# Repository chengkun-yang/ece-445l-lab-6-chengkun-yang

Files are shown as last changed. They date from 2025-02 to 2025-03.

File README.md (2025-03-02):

Review Assignment Due Date (https://classroom.github.com/a/TtMRZ3mh)
## 0 Repository Structure

The typical explanation for the repo structure. Lab specific instructions can be
found further below.

### 0.1 HW

The `hw` folder should contain your schematic and board files for your PCB or
circuits. In labs 1-5 and 10, you will be creating schematics for your circuit
in KiCad.

### 0.2 SW

The `sw` folder should contain your application firmware and software written
for the lab. The `sw/inc` folder contains firmware drivers written for you by
Professor Valvano. Feel free to write your own (in fact, in some labs, you may
be required to write your own).

You can place any other source files in the `sw` folder. TAs will look at the
files you create and/or modify for software quality and for running your
project.

### 0.3 Resources

A couple files are provided in the Resources folder so you don't have to keep
searching for that one TI document. Some of them are immediately useful, like
the TM4C datasheet. Others may be useful for your final project, like the
TM4C_System_Design_Guidelines page.

### 0.4 Git and Github

We will extensively use Git and Github for managing lab projects. This makes it
easier for TAs to grade and help debug the project by allowing us to see commit
histories, maintain a common project structure, and likewise, it makes it easier
for students to collaborate with partners, merge different codebases, and to
debug their work by having a history of commits.

Two common ways of using Git and Github are [Github Desktop](https://desktop.github.com/) and the [command line](https://git-scm.com/downloads).
[Tutorials](https://dev.to/mollynem/git-github--workflow-fundamentals-5496) are also abundant on the net for you to peruse. We've provided a cheatsheet for git
in the Resources folder.

It is highly recommended to make the most out of Git, even if you've never used
it before. Version control will save you a lot of suffering, and tools like Git
or SVN are ubiquitous in the industry.

A gitignore file is added to the root of this repo that may prevent specific
files from being tagged to the repo. This are typically autogenerated output
files we don't care about, but sometimes other stuff (like .lib files) falls
through that we want. Feel free to modify if necessary.

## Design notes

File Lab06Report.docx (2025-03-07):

Name: __Chengkun Yang

EID: __cy7496

Semester: Fall 2024

Course: ECE445L

A) Objectives:

1. In a few sentences, describe the purpose of the lab and the features of your alarm clock.

The purpose of this lab is to create a schematic for the alarm clock from lab 4, then converting it to a PCB and layout traces all within KiCAD. It features the tm4c chip instead of the full board and has reset / mode change switches. There are also plenty of bypass capacitors to prevent sudden changes in voltage along with routing to make the wire capacitance lower in critical subsystems.

B) Hardware Design Deliverables:

1. Deliverable 1: Using KiCad, create a schematic for your design. Include a screenshot in the space below.

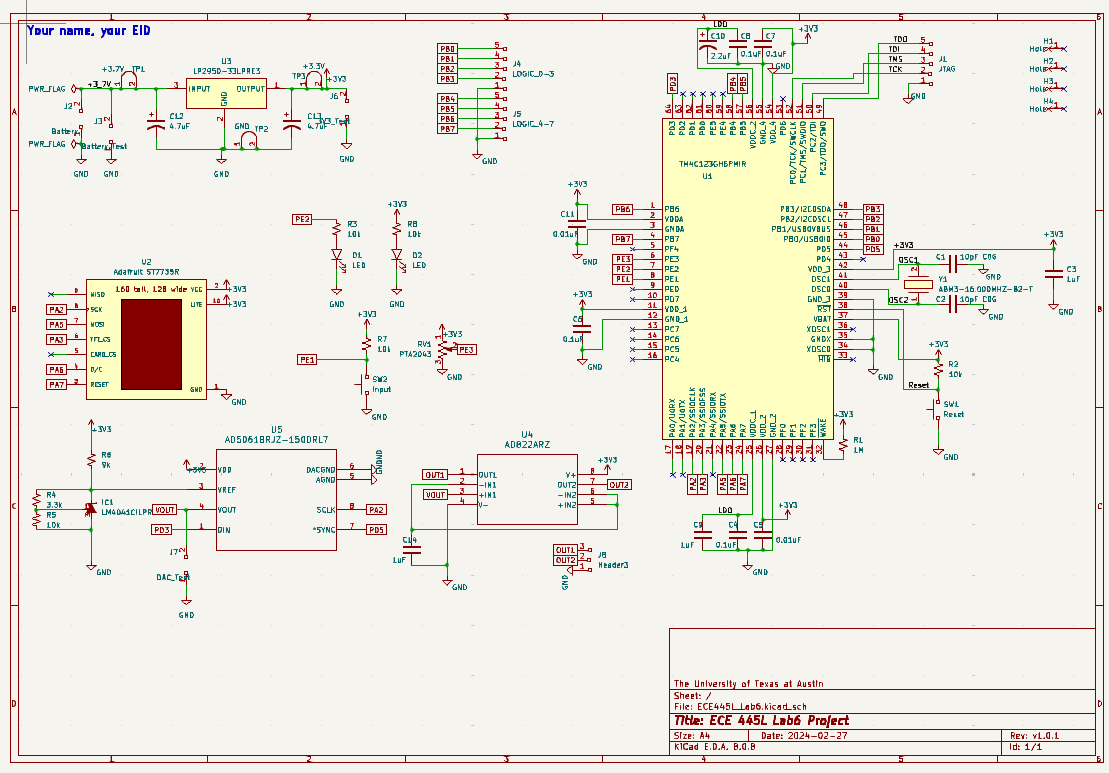
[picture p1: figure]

2. Deliverable 2: Using KiCad, create a Layout for your design. Include a screenshot in the space below.

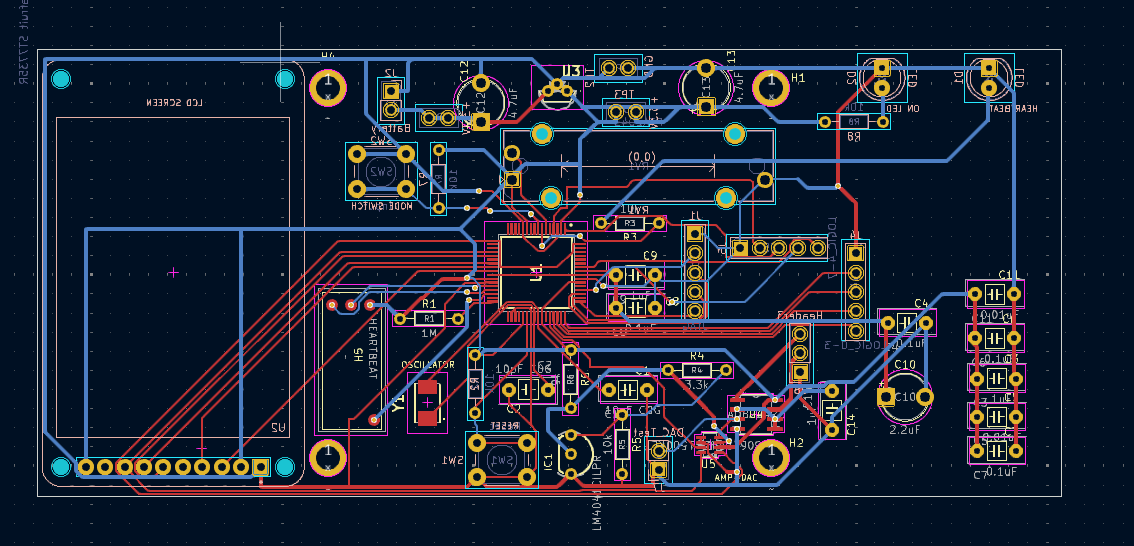
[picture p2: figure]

C) Software Design Deliverables:

1. I have pushed my project to GitHub for grading (Check box if true). ☒

D) Measurement Data:

1. Deliverable 3: Cardboard mockup of the PCB
2. Deliverable 4: I have updated the bill of materials (Check box if true). ☒
3. Deliverable 5: Estimated current usage

142.9 mA

4. Deliverable 6: JLC PCB Quote

$80.69

5. Deliverable 7 (4 or 8pt EC): Custom Symbol and Footprint

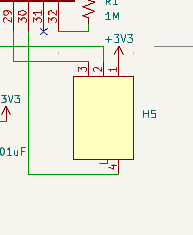
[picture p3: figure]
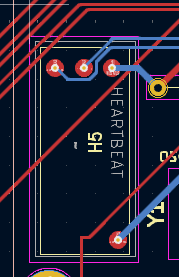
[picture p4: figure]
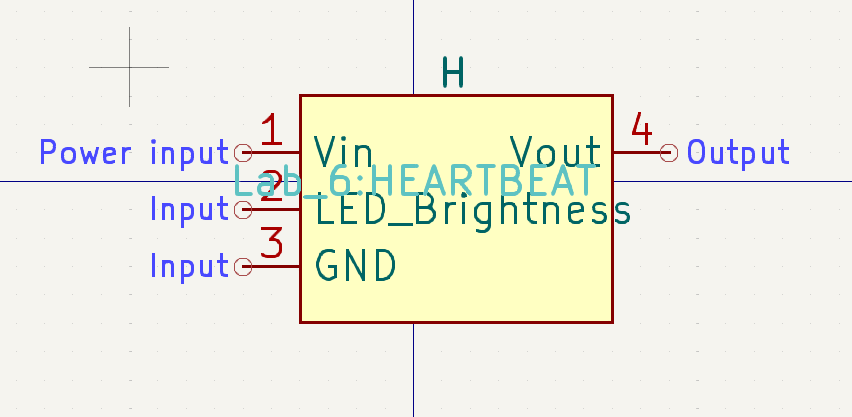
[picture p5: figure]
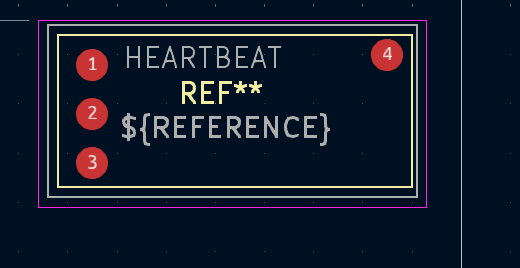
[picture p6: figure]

I did not show off my custom symbol during checkout, I just used the symbol editor and footprint editor in KiCAD and copied the footprint of other parts. For symbol I added 4 pins and labeled them as input/output/powerinput and for the footprint I added 3 layers of outline along with the silkscreen text and pins corresponding to the ones on the symbol.

E) Analysis and Discussion Questions:

1. Estimate how long the system you created would run on the 2600mA battery.

You do capacity/current to get around 18.2 hours.

2. Estimate the power dissipated through the LDO regulator knowing the current draw from downstream components and voltage drop across the regulator.

Since the voltage drop is 0.4V and the current draw is 142.9 mAh, the power dissipation is 0.0572W.

3. Examine the following excerpt from the datasheet for the MX1500 which has a nominal capacity of 2500mAh. Assuming you placed enough of these batteries in series to power your system, how long would the lifetime be? What happens to the lifetime of the battery when you double the current?

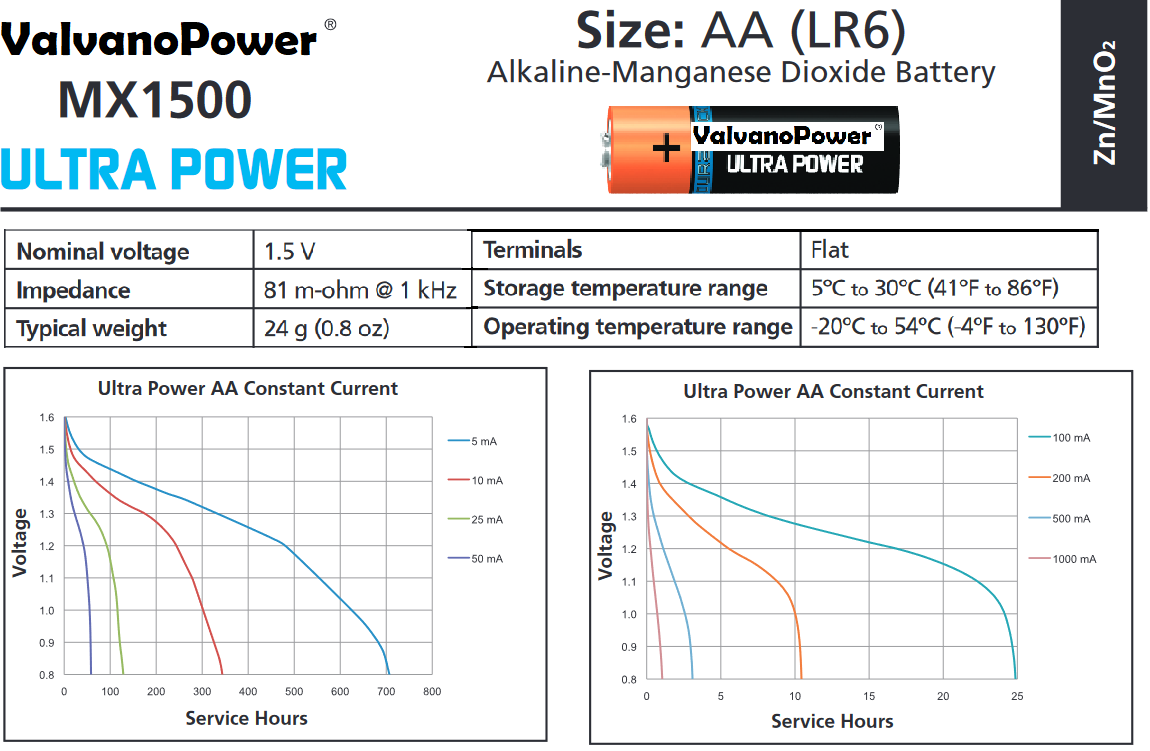
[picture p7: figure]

Since we need at least 3 in series to get >3.7V, the capacity would be 7500mAh which would be around 52.7 hours of lifetime. If the current is doubled, the lifetime halves.

4. Discuss the advantages and disadvantages of using an LDO versus a switching regulator.

LDOs are smaller in area and have low noise/output ripple. They are also cheaper and work with almost all power supplies with output variation. Unfortunately, they are less efficient, can only work with one predefined input voltage, can only output a single Vout lower than Vin, and work better with smaller current.

Lab 6 report ECE445L

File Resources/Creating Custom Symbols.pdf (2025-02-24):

## Creating Custom Symbols

## Contents

Creating Custom Symbols | 1

Introduction

KiCad is a powerful open-source software suite for electronic design automation (EDA). It offers a comprehensive set of tools for schematic capture and PCB layout. While KiCad comes with an extensive library of symbols and footprints, there are times when you may need to create custom symbols and footprints to suit specific components or devices not available in the standard libraries or online.

Creating custom symbols allows you to represent components accurately in your schematics, while custom footprints enable precise placement and routing of PCB components.

Creating a Custom Symbol

A symbol in KiCad represents a component on your schematic. Every component on a schematic must be precisely represented to ensure the functionality and reliability of the final product. While KiCad offers a vast library of pre-made symbols, there are instances where designers encounter unique components or specialized devices not covered by the standard offerings.

To create a symbol, open the symbol editor.

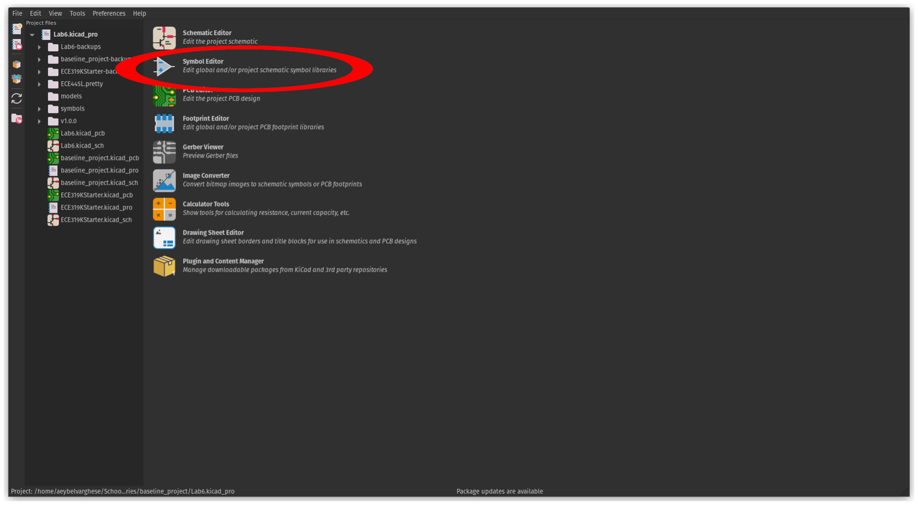
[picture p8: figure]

Figure 1: Main Menu

The KiCad Symbol Editor is a tool within the KiCad software suite specifically designed for creating and editing schematic symbols. It provides a user-friendly interface for designing graphical representations of electronic components, which are then used in schematics to illustrate circuit connections and layouts.

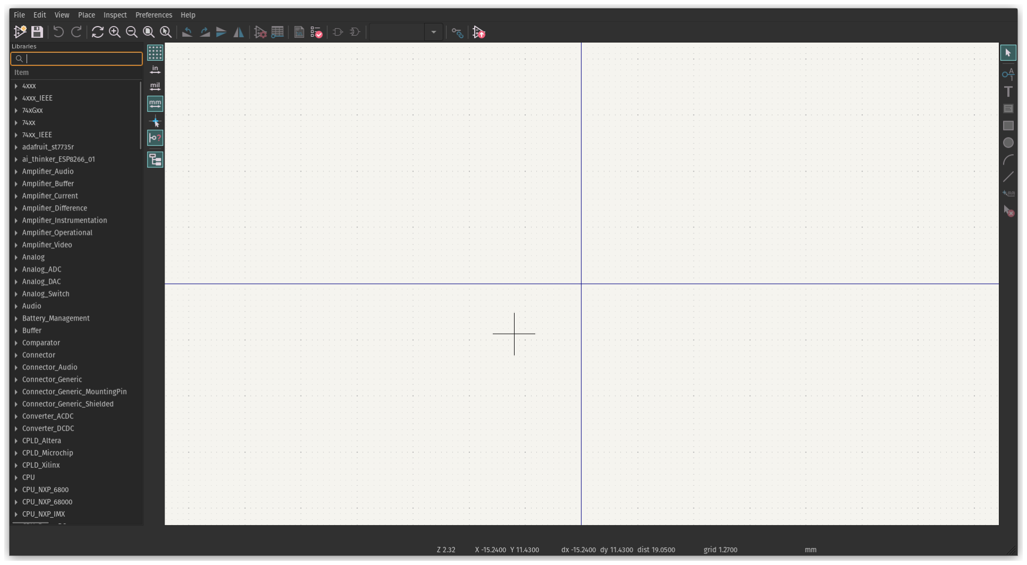
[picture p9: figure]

Figure 2: KiCad Symbol Editor

The Symbol Editor offers a graphical canvas where users can draw and manipulate schematic symbols using various drawing tools such as lines, arcs, polygons, and text boxes. The Symbol Editor allows users to save custom symbols to libraries for future use in other projects. Libraries can be organized and managed within KiCad to ensure easy access to custom symbols and efficient reuse across designs. Refer to the resource on adding libraries on more information regarding libraries.

When creating a symbol, it must be part of a library. We can either select a library to append a symbol to, or create a new library. To create a library, navigate to File → New Library, from here we can decide which symbol library table we want to add to, the global or project.

The global library table is shared amongst all your KiCad projects, while the project table is only for your currently open project. For this writeup, I am going to be adding it to the Project Table. When you press Ok, you can choose the location to save the “.kicad_sym” file which will contain your symbol library. You can choose any location you wish, although it is reccomended to have a folder dedicated for symbols organized in a reasonable matter. There is a “footprints” folder in the baseline project, and I will be storing the symbol library there. A entry in the symbol library table will be automatically made.

With a library selected in the left pane, press the “New Symbol Icon” or the Keyboard shortcut “N” to create a new symbol

Figure 3: Creating a symbol in the toolbar

Provide a name for the symbol, I am going to be creating a symbol for the MPU6050, (https://invensense.tdk.com/wp-content/uploads/2015/02/MPU-6000-Datasheet1.pdf) a IMU (Intertial Measurement Unit) from TDK InvenSense.

Creating symbols in KiCad involves designing graphical representations of electronic components to be used in schematics. Referring to datasheets during this process is crucial for accurately capturing the component’s electrical characteristics and pin configurations.

Referring to the pinout, we notice there are three categories of pins for this specific IC: power, communi-cation, and miscellaneous pins. We want to include all of these in our symbol. KiCad provides tools in the side toolbar to draw basic geometric shapes and describe pins.

Lets start by using the box tool to define the shape of our symbol.

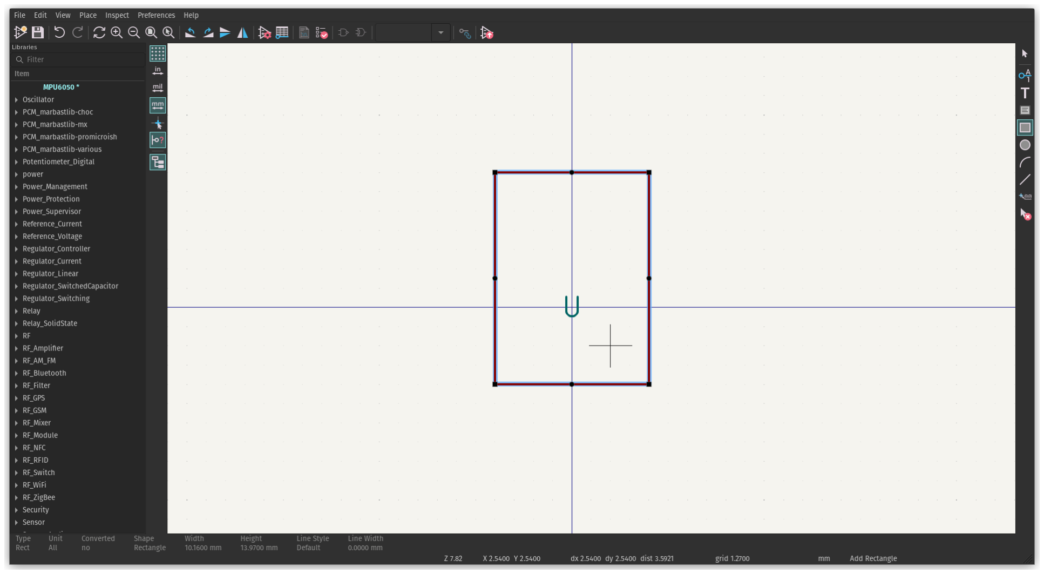
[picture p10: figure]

Figure 4: Box in Symbol Editor

With the shape of our pin assigned lets start adding pins. Select the “Add a Pin” button on the side toolbar, or press “P”.

When you press “Add a pin” in the KiCad Symbol Editor, you are prompted with several options to configure the properties of the pin being added to the symbol. These options allow you to define the electrical characteristics and behavior of the pin within the schematic symbol.

1. Name: This field allows you to specify the name of the pin, which is typically a descriptive label indicating the function or purpose of the pin within the component. Refer to the datasheet of the component for the name
2. Number: Here, you can assign a unique number to the pin. Pin numbers are used to identify individual pins within the symbol and are often based on the component’s datasheet or industry standards.
3. Orientation: This option determines the direction in which the pin is oriented within the symbol. You can choose from various orientations such as left, right, up, down.
4. Length: Specifies the length of the pin’s graphical representation within the symbol. This helps to visually distinguish pins of different lengths and aids in aligning pins with their corresponding connection points in the schematic.
5. Electrical Type: Defines the electrical characteristics of the pin, such as whether it is an input, output, bidirectional, power, or other special types. Selecting the appropriate electrical type ensures correct behavior during circuit simulation and layout as well as good for organization.
6. Visible: Determines whether the pin is visible or hidden in the symbol. Hidden pins are often used for internal connections or other purposes where the pin should not be displayed on the schematic.
7. Pin Function: This option allows you to specify additional information about the pin’s function or behavior, such as whether it is a clock input, reset signal, or other specialized function. This information aids in documentation and understanding the purpose of each pin within the symbol.

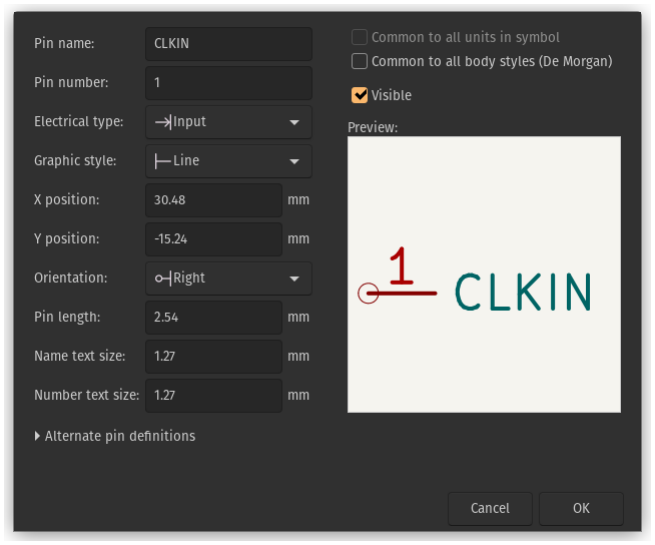
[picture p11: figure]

Figure 5: Describing a pin

Once we submit the options for the pin, we can place the pin down on our symbol.

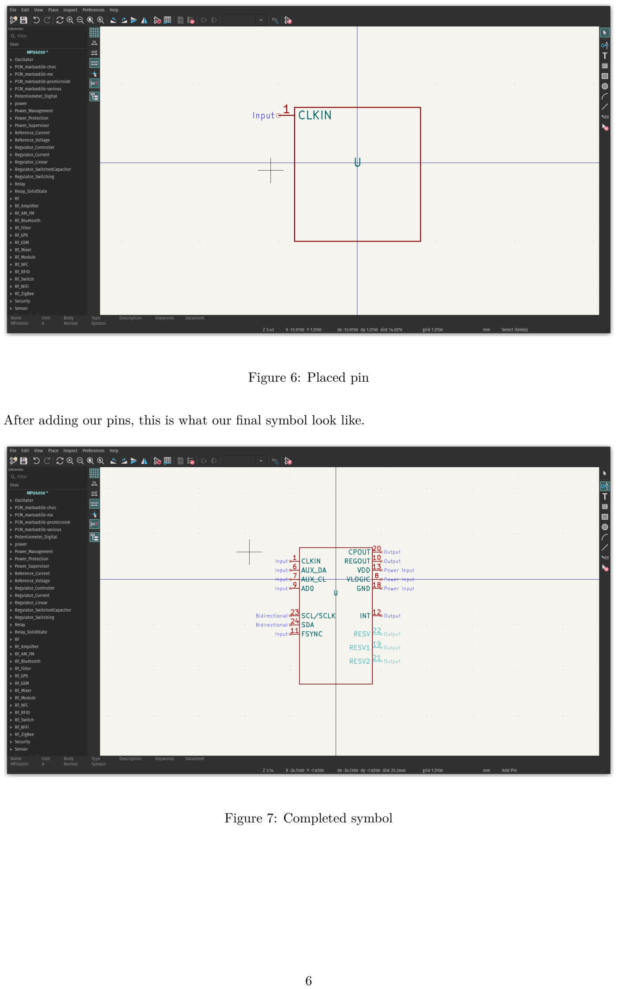
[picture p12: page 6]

Figure 6: Placed pin

After adding our pins, this is what our final symbol look like.

Figure 7: Completed symbol

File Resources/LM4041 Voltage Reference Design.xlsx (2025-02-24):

Goal: design a shunt reference circuit
Jonathan Valvano, EE445L
Desired Vz | 1.5 | volts | 1) pick a desired reference voltage Vz (volts)
Vref | 1.233 | volts | LM4041 parameter
R1 | 47 | kohm | 2) choose a standard resistance value (kohm)
best R2 | 10.17761557 | kohm
Pick R2 | 10 | kohm | 3) pick a standard value for R2 close to best R2
Actual Vref | 1.495340426 | volts | Vz=Vref(1+R2/R1)
Vs | 3.3 | volts | V supply
Rin | 2 | kohm | 4) estimate input impedence on Vz (e.g., to DAC)
Iz | 0.08 | mA | LM4041 parameter
Iref | 0.02623404255 | mA | Vz/(R1+R2), Ohms Law, current through R1,R2
IL | 0.7476702128 | mA | Vz/Rin, Ohms Law, current through Rin
I total | 0.8539042553 | mA | Iz+Iref+IL
max Rs | 2.113421456 | kohm | (Vs-Vz)/Itotal
 |  |  | 5) choose Rs less than max Rs

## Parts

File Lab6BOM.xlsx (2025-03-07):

Bill of Materials |  |  | Lab 6
ECE445L Fall 2024 |  |  | $80.69
Qty Note | REF DES Note (http://projects.ece.utexas.edu/valvano/wiki/doku.php?id=pcbartist:schematics)
Quantity | REF DES | Type | Description | Manufacturer | Mfg. P/N | Distributor | P/N | Unit cost | Cost | Estimated Current | Inventory
1 | J2 | BAT | Li-ion Cylindrical 3.7V 2600mAh Battery | Tenergy | 18650 |  |  | $8.00 | $8.00 |  | https://power.tenergy.com/tenergy-li-ion-18650-cylindrical-3-7v-2600mah-flat-top-rechargeable-battery-ul-listed-mh48285
1 | U5 | DAC | 16bit 4LSB buffered DAC in SOT23 | Analog Devices | AD5061BRJZ-1500RL7 | Mouser | 584-AD5061BRJZ1500R7 | $10.15 | $10.15 | 1.2mA
1 | U4 | AMP | IC OPAMP GP 2 CIRCUIT 8SOIC | Analog Devices | AD822ARZ | DigiKey | 505-AD822ARZ-ND | $12.33 | $12.33 | 20mA
1 | N/A | BOX | Enclosures, Boxes, & Cases 1593Y W/ALUM PANEL BLACK | Hammond | 1593YALBK | Mouser | 546-1593YALBK | $9.83 | $9.83
2 | SW1, SW2 | SW | SWITCH TACTILE SPST-NO 0.05A 12V | C&K | PTS526SK15SMTR2 LFS | DigiKey | CKN12221-1-ND | $0.13 | $0.26
1 | U2 | DIS | GRAPHIC DISPLAY TFT RGB 1.8" | Adafruit | 358 | DigiKey | 1528-1536-ND | $19.95 | $19.95 | 0.7mA
1 | U3 | LDO | IC REG LINEAR 3.3V 100MA TO92-3 | TI | LP2950-33LPE3 | DigiKey | 296-26120-ND | $1.15 | $1.15 | 100mA
2 | D1, D2 | LED | LED RED DIFFUSED T-1 3/4 T/H | Kingbright | WP7113ID | DigiKey | 754-1264-ND | $0.21 | $0.42 | 20mA
1 | RV1 | POT | SLIDE POT 10K OHM 0.1W TOP 20MM | Bourns | PTA2043-2015CPB103 | DigiKey | PTA2043-2015CPB103-ND | $1.44 | $1.44
1 | IC1 | VREF | IC VREF SHUNT ADJ 0.5% TO92-3 | TI | LM4041CILPR | DigiKey | 296-22173-1-ND - Cut Tape (CT) | $1.06 | $1.06
5 | R2, R3, R5, R7, R8 | RES | RES 10K OHM 1% 1/4W AXIAL | YAGEO | MFR-25FRF52-10K | DigiKey | 13-MFR-25FRF52-10KCT-ND | $0.10 | $0.50
4 | R4, R6 | RES | RES 3K OHM 5% 1/4W AXIAL | Stackpole Electronics Inc | CF14JT3K00 | DigiKey | CF14JT3K00CT-ND | $0.10 | $0.40
1 | U1 | IC | IC MCU 32BIT 256KB FLASH 64LQFP | TI | TM4C123GH6PMI | DigiKey | 296-35848-ND | $13.02 | $13.02 | 1mA
2 | C12, C13 | CAP | CAP CER 4.7UF 10V X5R 0603 | Samsung Electro-Mechanics | CL10A475KP8NNNC | DigiKey | 1276-1044-1-ND | $0.08 | $0.16
4 | C4, C6, C7, C8 | CAP | CAP CER 0.1UF 10V X7R 0402 | Samsung Electro-Mechanics | CL05B104KP5NNNC | DigiKey | 1276-1002-1-ND | $0.08 | $0.32
3 | C3, C9, C14 | CAP | CAP CER 1UF 25V X7R 0603 | Samsung Electro-Mechanics | CL10B105KA8NNNC | DigiKey | 1276-1184-1-ND | $0.08 | $0.24
1 | C10 | CAP | CAP CER 2.2UF 10V X7R 0603 | Samsung Electro-Mechanics | CL10B225KP8NNNC | DigiKey | 1276-1134-1-ND | $0.08 | $0.08
2 | C5, C11 | CAP | CAP CER 0.01UF 10V X7R 0201 | Taiyo Yuden | MAASL063SB7103MFCA01 | DigiKey | 587-MAASL063SB7103MFCA01CT-ND | $0.11 | $0.22
2 | C1, C2 | CAP | CAP CER 10PF 50V C0G/NP0 0402 | Murata Electronics | GRM1555C1H100FA01D | DigiKey | 490-6186-1-ND | $0.10 | $0.20
1 | Y1 | OSC | CRYSTAL 16.0000MHZ 18PF SMD | Abracon LLC | ABM3-16.000MHZ-B2-T | DigiKey | 535-9103-1-ND | $0.96 | $0.96
 |  |  |  |  |  |  |  |  |  |  |  | 5 CD
 |  |  |  |  |  |  |  |  |  |  | http://www.kemet.com/kemet/web/homepage/kechome.nsf/vapubfiles/F3101_GoldMax.pdf/$file/F3101_GoldMax.pdf

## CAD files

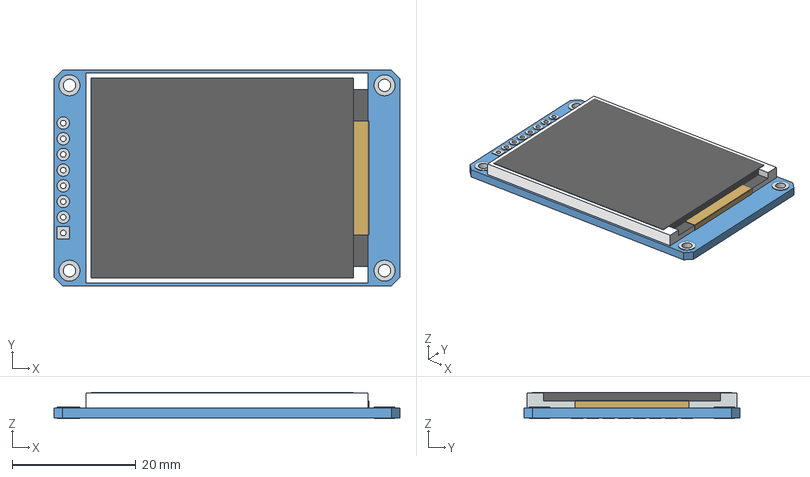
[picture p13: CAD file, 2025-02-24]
hw/Part Libraries/models/adafruit_st7735r.stp
56.0 x 35.0 x 4.25 mm

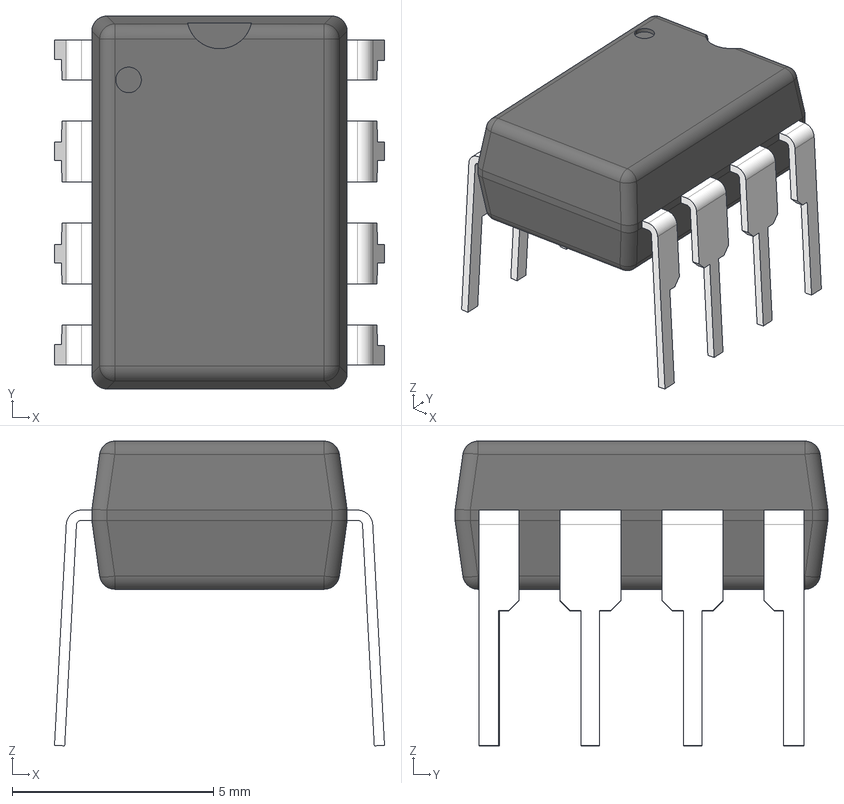
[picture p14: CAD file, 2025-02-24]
hw/Part Libraries/models/ti_TLV5618AIP.stp
8.20 x 9.27 x 7.58 mm
BODY_P0008A
LEAD_P0008A x 4
LD_LHALF_P0008A x 2
LD_RHALF_P0008A x 2

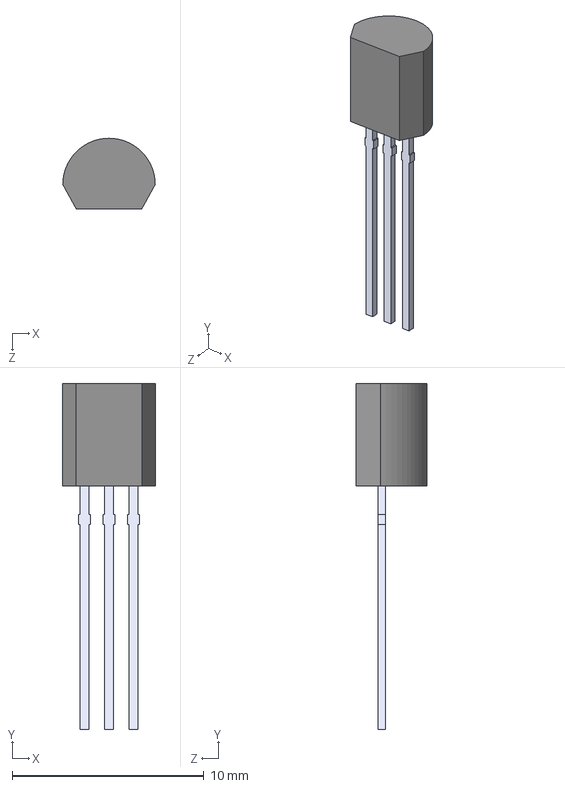
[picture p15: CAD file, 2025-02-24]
hw/Part Libraries/models/ti_LM4041CILPR.step
4.82 x 18.0 x 3.68 mm

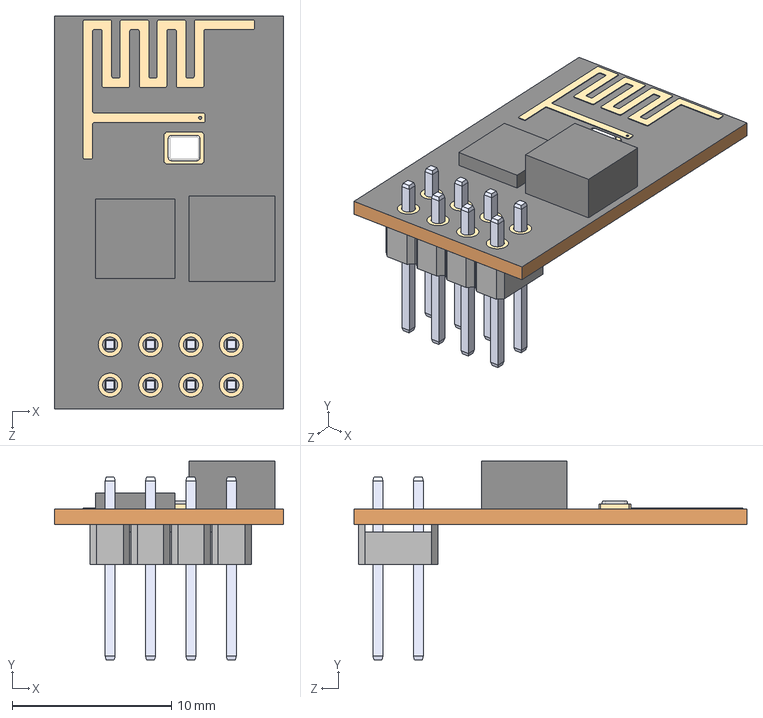
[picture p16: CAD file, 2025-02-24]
hw/Part Libraries/models/ai_thinker_ESP8266-01.step
14.4 x 12.5 x 24.7 mm

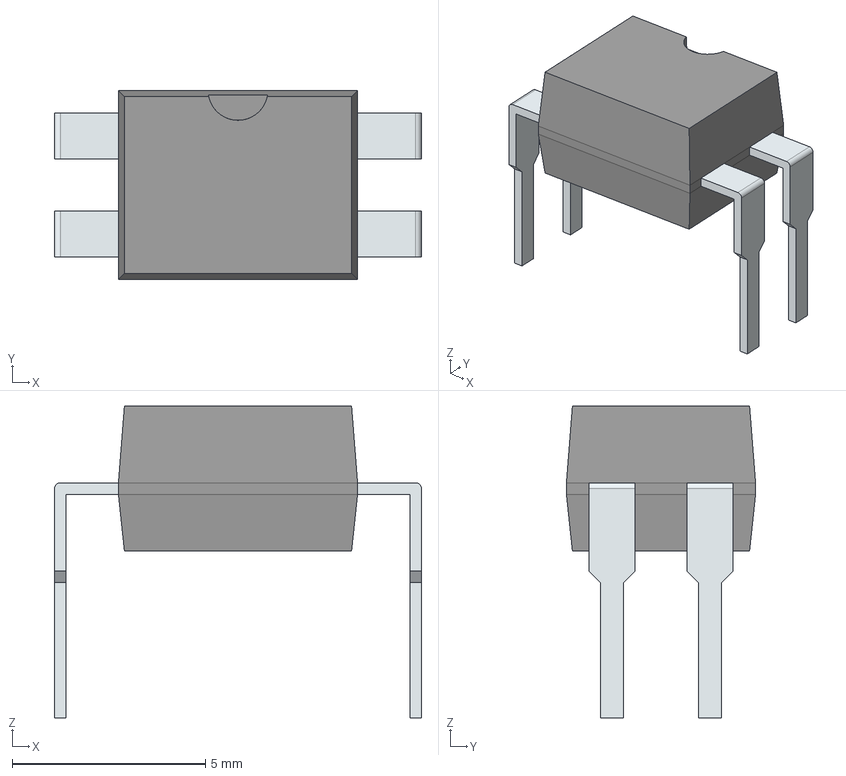
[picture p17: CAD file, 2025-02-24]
hw/Part Libraries/models/vishay_IRLD024PBF.stp
9.51 x 4.90 x 8.07 mm
PinsArrayLR

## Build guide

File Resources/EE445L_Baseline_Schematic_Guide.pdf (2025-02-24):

# EE445L – Fall 2021

Lab Baseline Schematic Guide: Rev 10-1-2021 | Page 1

### McDermott & Valvano

This semester we have decided to standardize the I/O Pin assignment to make remote debugging a little

### bit easier for the TAs. The standardized Signal and Port assignments are listed below:

PORT | SIGNAL NAME | TM4C PORT ASSIGNMENT | NOTES
Port-A[2] | ST7735_SCK | SSI0_SCK | SSI interface to the ST7735 LCD
Port-A[3] | ST7735_TFT_CS | SSI0_SS
Port-A[4] | ST7735_MISO | SSI0_MISO
Port-A[5] | ST7735_MOSI | SSI0_MOSI
Port-A[6] | ST7735_DC | GPIO
Port-A[7] | ST7735_RST | GPIO
PORT | SIGNAL NAME | TM4C PORT ASSIGNMENT | NOTES
Port-B[0] | ST7735_CARD_CS | GPIO | ST7735 SDCARD Chip Select
Port-B[1] | PB1 | GPIO | Used for simple speaker
Port-B[2] | PB2 | GPIO/I2C0_SCK | Primarily GPIO, can be used for I2C
Port-B[3] | PB3 | GPIO/I2C0_SDA
Port-B[4] | TACH2 | T1_CCP0 | Tach Input for Lab-10
Port-B[5] | PB5 | GPIO/AIN_11 | GPIO or Analog input
Port-B[6] | PWM | M0_PWM0 | PWM control for Lab-10
Port-B[7] | PB7 | GPIO/PWM1
PORT | SIGNAL NAME | TM4C PORT ASSIGNMENT | NOTES
Port-C[4] | UP | GPIO | Used for switches in Lab 3
Port-C[5] | RIGHT | GPIO
Port-C[6] | LEFT | GPIO
Port-C[7] | DOWN | GPIO
PORT | SIGNAL NAME | TM4C PORT ASSIGNMENT | NOTES
Port-D[0] | SSI1_SCK | SSI1_SCK | SCK to TLV5616 DAC
Port-D[1] | SSI1_FS | SSI1_FS | SS/FS to TLV5616 DAC
Port-D[2] | PD2 | AIN_5 | Used to monitor DAC_OUT
Port-D[3] | SSI1_MOSI | SSI1_MOSI | MOSI to TLV5616 DAC
Port-D[6] | PD6 | GPIO | Can be used as alternate UART Port
Port-D[7] | PD7 | GPIO
PORT | SIGNAL NAME | TM4C PORT ASSIGNMENT | NOTES
Port-E[0] | 8266_GPIO_2 | GPIO | Status signal 8266 WiFi
Port-E[1] | RSTB_8266 | GPIO | Reset signal to 8266 WiFi
Port-E[2] | AIN_1 | AIN1 | Used for Audio Input Lab-9
Port-E[3] | GPIO | GPIO
Port-E[4] | 8266_TX 8266_RX | U5_RX U5_TX | UART TXD/RXD to 8266 WiFi Port-E[5]
PORT | SIGNAL NAME | TM4C PORT ASSIGNMENT | NOTES
Port-F[0] | LAUNCHPAD_SW2 | RESERVED for Launchpad | Mode Switch
Port-F[1] | RED_LED | | Red LED on LaunchPad
Port-F[2] | BLUE_LED | | Blue LED on LaunchPad
Port-F[3] | GREEN_LED | | Green LED on LaunchPad
Port-F[4] | LAUNCHPAD_SW1 | | Mode Switch
The baseline schematic printout is shown on the next two pages. Use this as the starting point for Eagle

### Schematics

Lab Baseline Schematic Guide: Rev 10-1-2021 | Page 2

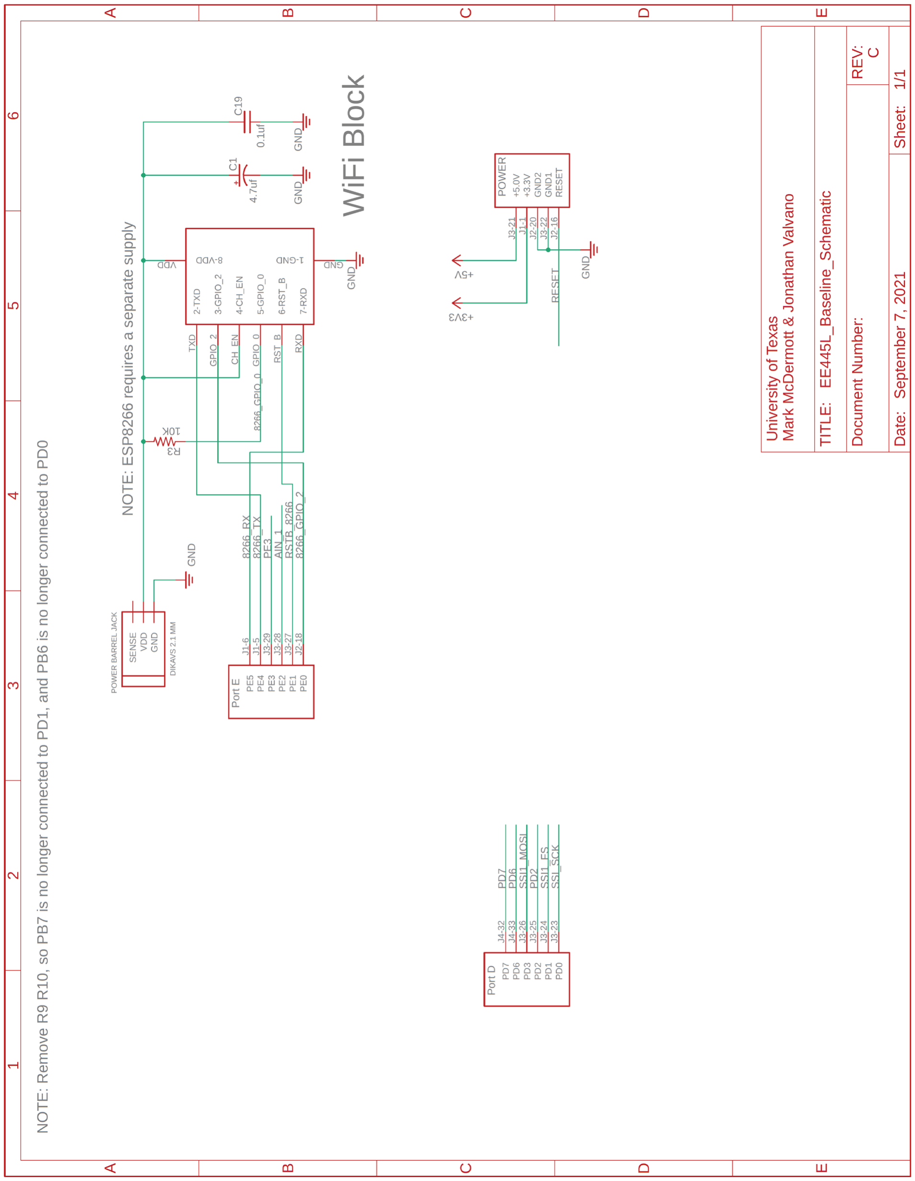
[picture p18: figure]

Lab Baseline Schematic Guide: Rev 10-1-2021 | Page 3

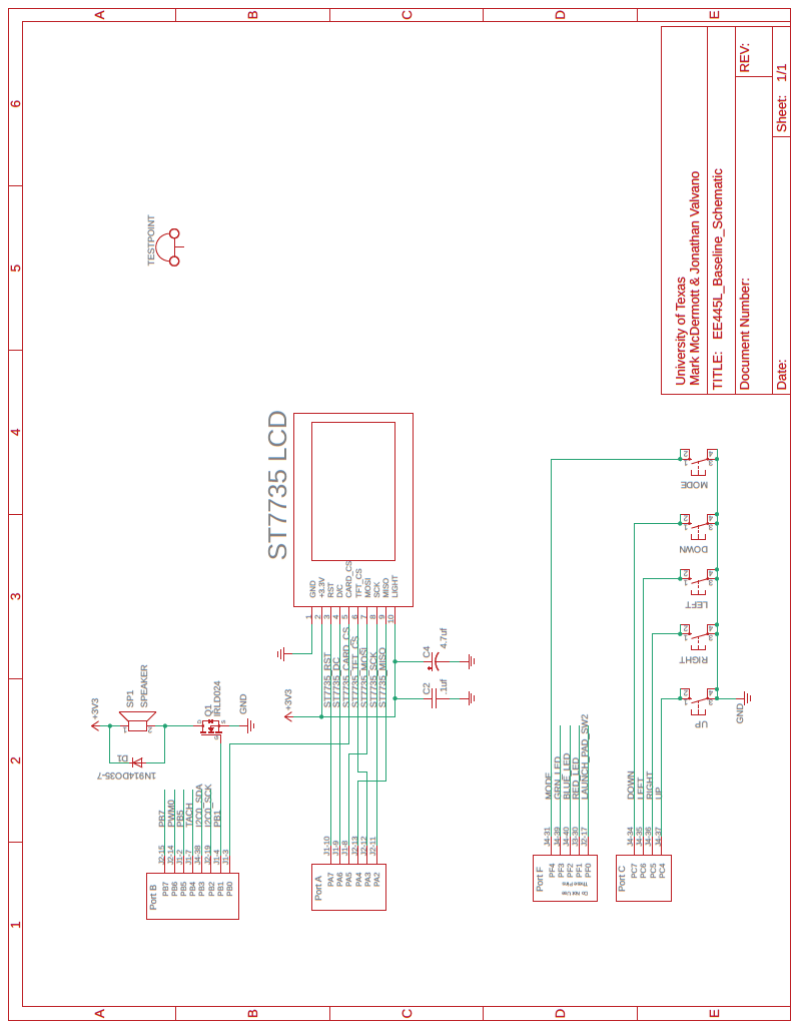
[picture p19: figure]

Lab Baseline Schematic Guide: Rev 10-1-2021 | Page 4

### PORT Initialization

Do not use this code without confirming that it does what you need it to do.

// ---------------------------------------------------------------------------//
// File name: Unified_Port_Init.c
//
// Author: | Mark McDermott
// Orig gen date: July 12, 2020
// Last update: August 17, 2020
//
// Description: This is the unified Port initialization routine 445L Labs
//
// Usage: | Call Lab_Brd_Port_Init () if you want to initialize all ports (preferred)
// | Call the individual port inits as needed.
//
// ---------------------------------------------------------------------------

#include "inc/tm4c123gh6pm.h"

#include "inc/Lab_Brd_Port_Init.h"

// --------------------------- | Port_Init | ------------------------------

void Lab_Brd_Port_Init(void){
Port_A_Init();
Port_B_Init();
Port_C_Init();
Port_D_Init();
Port_E_Init();
Port_F_Init();
}

// ----------------------------------------------------------------------------
// ---------------- | PORT A Initialization | --------------------------------
// ----------------------------------------------------------------------------//
// Port A drives the ST7735 LCD
//
// Backlight (pin 10) connected to +3.3 V
// MISO | (pin 9) connected to PA4
// SCK | (pin 8) connected to PA2 (SSI0Clk)
// MOSI | (pin 7) connected to PA5 (SSI0Tx)
// TFT_CS | (pin 6) connected to PA3 (SSI0Fss)
// CARD_CS | (pin 5) connected to PB0 (GPIO)
// Data/CMD (pin 4) connected to PA6 (GPIO)
// RESET | (pin 3) connected to PA7 (GPIO)
// VCC | (pin 2) connected to +3.3 V
// Gnd | (pin 1) connected to ground
//

void Port_A_Init(void){

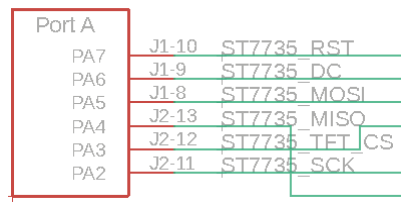
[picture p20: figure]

SYSCTL_RCGCSSI_R | |= 0x01; | // Activate SSI0
SYSCTL_RCGCGPIO_R | |= 0x01; | // Activate port A
while((SYSCTL_PRGPIO_R & 0x01)==0){}; | // allow time for clock to start
GPIO_PORTA_DIR_R | |= 0xC8; | // make PA3,6,7 out
GPIO_PORTA_AFSEL_R | &= ~0xC8; | // disable alt funct on PA3,6,7

Lab Baseline Schematic Guide: Rev 10-1-2021 | Page 5
GPIO_PORTA_DEN_R | |= 0xC8; | // enable digital I/O on PA3,6,7

// configure PA3,6,7 as GPIO
GPIO_PORTA_PCTL_R | = (GPIO_PORTA_PCTL_R
| & 0x00FF0FFF)
| + 0x00000000;
GPIO_PORTA_AMSEL_R | &= ~0xC8; | // disable analog functionality on PA3,6,7

// initialize SSI0
GPIO_PORTA_AFSEL_R | |= 0x2C; | // enable alt funct on PA2,3,5
GPIO_PORTA_DEN_R | |= 0x2C; | // enable digital I/O on PA2,3,5

// configure PA2,3,5 as SSI
GPIO_PORTA_PCTL_R | = (GPIO_PORTA_PCTL_R
| & 0xFF0F00FF)
| + 0x00202200;
GPIO_PORTA_AMSEL_R | &= ~0x2C; | // disable analog functionality on PA2,3,5
SSI0_CR1_R | &= ~SSI_CR1_SSE; | // disable SSI
SSI0_CR1_R | &= ~SSI_CR1_MS; | // master mode

// configure for system clock/PLL baud clock source
SSI0_CC_R | = (SSI0_CC_R&~SSI_CC_CS_M)
| + SSI_CC_CS_SYSPLL;

// clock divider for 8 MHz SSIClk (80 MHz PLL/24) // SysClk/(CPSDVSR*(1+SCR))
// 80/(10*(1+0)) = 8 MHz (slower than 4 MHz)
SSI0_CPSR_R | = (SSI0_CPSR_R
&~SSI_CPSR_CPSDVSR_M)
| + 10; | // must be even number

// SCR = 0 (8 Mbps data rate)
// SPH = 0
// SPO = 0
SSI0_CR0_R | &= ~(SSI_CR0_SCR_M
| | SSI_CR0_SPH
| | SSI_CR0_SPO);

// FRF = Freescale format
SSI0_CR0_R | = (SSI0_CR0_R
| &~SSI_CR0_FRF_M)
| + SSI_CR0_FRF_MOTO;

// DSS = 8-bit data
SSI0_CR0_R | = (SSI0_CR0_R
| &~SSI_CR0_DSS_M)
| + SSI_CR0_DSS_8;
// enable SSI
SSI0_CR1_R | |= SSI_CR1_SSE;

}

Lab Baseline Schematic Guide: Rev 10-1-2021 | Page 6

// ----------------------------------------------------------------------------
// ---------------- | PORT B Initialization | --------------------------------
// ----------------------------------------------------------------------------
//
// PB7 = GPIO/M0PWM1
// PB6 = PWM Output to Motor (M0PWM0)
// PB5 = GPIO/AIN11
// PB4 = Timer Capture input (TACH) // PB3 = GPIO/I2C_SDA
// PB2 = GPIO/I2C0_SCL
// PB1 = GPIO
// PB0 = ST7735 Card CS

void Port_B_Init(void){

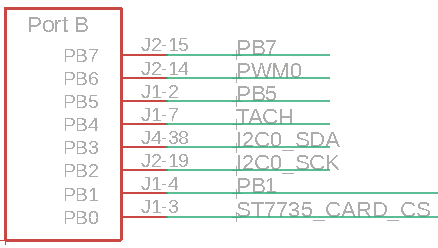
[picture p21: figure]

SYSCTL_RCGCPWM_R | |= 0x01; | // activate PWM0
SYSCTL_RCGCGPIO_R | |= 0x02; | // activate port B
while((SYSCTL_PRGPIO_R & 0x02) == 0){}; | // Wait

// --------------- Initialize PB7 as M0PWM1 -----------------------

GPIO_PORTB_AFSEL_R | |= 0x80; | // enable alt funct on PB7
GPIO_PORTB_PCTL_R | &= ~0xF0000000; | // configure PB7 as M0PWM1
GPIO_PORTB_PCTL_R | |= 0x40000000;
GPIO_PORTB_AMSEL_R | &= ~0x80; | // disable analog functionality on PB7
GPIO_PORTB_DEN_R | |= 0x80; | // enable digital I/O on PB7

// --------------- Initialize PB6 as M0PWM0 -----------------------
GPIO_PORTB_AFSEL_R | |= 0x40; | // enable alt funct on PB6
GPIO_PORTB_PCTL_R | &= ~0x0F000000; | // configure PB6 as PWM0
GPIO_PORTB_PCTL_R | |= 0x04000000;
GPIO_PORTB_AMSEL_R | &= ~0x40; | // disable analog functionality on PB6
GPIO_PORTB_DEN_R | |= 0x40; | // enable digital I/O on PB6

// --------------- Initialize PB5 as AIN11 -----------------------
GPIO_PORTB_DIR_R | &= ~0x20; | // make PB5 input
GPIO_PORTB_AFSEL_R | |= 0x20; | // enable alternate function on PB5
GPIO_PORTB_DEN_R | &= ~0x20; | // disable digital I/O on PB5
GPIO_PORTB_AMSEL_R | |= 0x20; | // enable analog functionality on PB5

// ----------------- Initialize PB4 as Timer Capture input (T1CCP0) ---------
GPIO_PORTB_DIR_R | &= ~0x10; | // make PB4 input
GPIO_PORTB_AFSEL_R | |= 0x10; | // enable alt funct on PB4
GPIO_PORTB_DEN_R | |= 0x10; | // enable digital I/O on PB4
| | // configure PB4 (T1CCP0)
GPIO_PORTB_PCTL_R | = (GPIO_PORTB_PCTL_R
| & 0xFFF0FFFF)
| + 0x00070000;
GPIO_PORTB_AMSEL_R | &= ~0x10; | // disable analog functionality on PB4

// ----------------- Initialize PB3-0 as GPIO ---------
GPIO_PORTB_PCTL_R | &= ~0x0000FFFF; | // GPIO
GPIO_PORTB_DIR_R | |= 0x0F; | // make PB3-0 out
GPIO_PORTB_AFSEL_R | &= ~0x0F; | // regular port function
GPIO_PORTB_DEN_R | |= 0x0F; | // enable digital I/O on PB3-0
GPIO_PORTB_AMSEL_R | &= ~0x0F; | // disable analog functionality on PB3-0
}

Lab Baseline Schematic Guide: Rev 10-1-2021 | Page 7

// ----------------------------------------------------------------------------
// ---------------- | PORT C Initialization | --------------------------------
// ----------------------------------------------------------------------------
//
// PC4 = UP switch
// PC5 = RIGHT switch
// PC6 = LEFT switch
// PC7 = DOWN switch
//

void Port_C_Init(void){

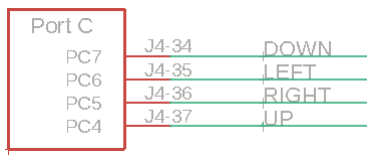
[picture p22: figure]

SYSCTL_RCGCGPIO_R | |= 0x04; | // Activate clock for Port C
while((SYSCTL_PRGPIO_R & 0x04) != 0x04){}; // Allow time for clock to start
GPIO_PORTC_PCTL_R | &= ~0xFFFF0000; | // regular GPIO
GPIO_PORTC_AMSEL_R | &= ~0xF0; | // disable analog function
GPIO_PORTC_DIR_R | &= ~0xF0; | // inputs on PC7-PC4
GPIO_PORTC_AFSEL_R | &= ~0xF0; | // regular port function
GPIO_PORTC_DEN_R | |= 0xF0; | // enable digital port
}

Lab Baseline Schematic Guide: Rev 10-1-2021 | Page 8

// ----------------------------------------------------------------------------
// ---------------- | PORT D Initialization | --------------------------------
// ----------------------------------------------------------------------------
//
// PD7 = GPIO/U2TX
// PD6 = GPIO/U2RX
// PD5 = Reserved for LaunchPad // PD4 = Reserved for Launchpad // PD3 = SSI1_MOSI (to TLV5616) // PD2 = AIN5
// PD1 = SSI1_FS/CS (to TLV5616) // PD0 = SSI1_SCK (to TLV5616)

void Port_D_Init(void){

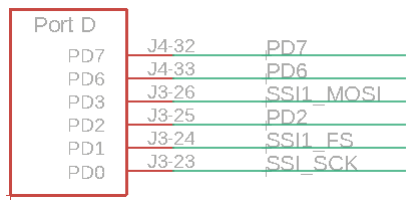
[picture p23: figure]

SYSCTL_RCGCGPIO_R | |= 0x08; | // activate port D
while((SYSCTL_PRGPIO_R & 0x08)==0){}; | // allow time for clock to stabilize

// --------------- Initialize PB7 as U2TX, PB6 as U2RX -----------------------

GPIO_PORTD_LOCK_R | = 0x4C4F434B; | // unlock REQUIRED for PD7
GPIO_PORTD_CR_R | |= 0xC0; | // commit PD6, PD7
GPIO_PORTD_AMSEL_R | &= ~0xC0; | // disable analog functionality on PD6, PD7
GPIO_PORTD_AFSEL_R | |= 0xC0; | // enable alternate function on PD6, PD7
GPIO_PORTD_DEN_R | |= 0xC0; | // enable digital on PD6, PD7 (PD6 is U2RX, PD7 is
U2TX)
GPIO_PORTD_PCTL_R =(GPIO_PORTD_PCTL_R
& 0x00FFFFFF)
| 0x11000000; // configure PD6, PD7 as UART

// --------------- Initialize PD2 as AIN5 ----------------------------------

GPIO_PORTD_DIR_R | &= ~0x04; | // make PD2 input
GPIO_PORTD_AFSEL_R | |= 0x04; | // enable alternate function on PD2
GPIO_PORTD_DEN_R | &= ~0x04; | // disable digital I/O on PD2
GPIO_PORTD_AMSEL_R | |= 0x04; | // enable analog functionality on PD2
// --------------- Initialize PD3,1,0 as SSI1 MOSI, FS & SCK ----------------
GPIO_PORTD_AMSEL_R | &= ~0x0B; | // disable analog functionality on PD
GPIO_PORTD_AFSEL_R | |= 0x0B; | // enable alt funct on PD3,1,0
GPIO_PORTD_DEN_R | |= 0x0B; | // enable digital I/O on PD3,1,0
GPIO_PORTD_PCTL_R | = (GPIO_PORTD_PCTL_R
& 0xFFFF0F00)
+ 0x00002022;
}

Lab Baseline Schematic Guide: Rev 10-1-2021 | Page 9

// ----------------------------------------------------------------------------
// ---------------- | PORT E Initialization | --------------------------------
// ----------------------------------------------------------------------------
//
// PE5 = 8266_RX (U5TX)
// PE4 = 8266_TX (U5RX)
// PE3 = GPIO
// PE2 = AIN_1 (Audio Input) // PE1 = 8266_8266
// PE0 = 8266_ GPIO_2

void Port_E_Init(void){

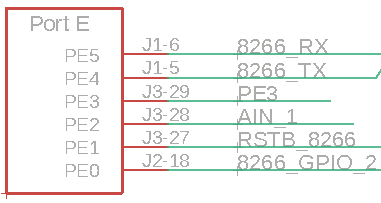
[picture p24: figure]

SYSCTL_RCGCGPIO_R | |= 0x10; | // activate port E
while((SYSCTL_PRGPIO_R & 0x10)==0){};

// --------------- Initialize PE5 as U5TX, PE4 as U5RX -----------------------

GPIO_PORTE_AFSEL_R | |= 0x30; | // enable alt funct on PE5-4
GPIO_PORTE_DEN_R | |= 0x30; | // enable digital I/O on PE5-4
| | // configure PE5-4 as UART
GPIO_PORTE_PCTL_R | = (GPIO_PORTE_PCTL_R
| & 0xFF00FFFF)
| + 0x00110000;
GPIO_PORTE_AMSEL_R | &= ~0x30; | // disable analog functionality on PE
// --------------- Initialize PE3,1,0 as GPIO ---------------------------------
GPIO_PORTE_DIR_R | |= 0x0A; | // output digital I/O on PE3,1
GPIO_PORTE_DIR_R | &= ~0x01; | // input digital I/O on PE0
GPIO_PORTE_AMSEL_R | &= ~0x0B; | // disable analog functionality on PE3,1,0
GPIO_PORTE_AFSEL_R | &= ~0x0B; | // disable alt funct on PE3,1,0
GPIO_PORTE_DEN_R | |= 0x0B; | // enable digital I/O on PE3,1,0
GPIO_PORTE_PCTL_R | = (GPIO_PORTE_PCTL_R
| & 0xFFFF0F00);
// --------------- Initialize PE2 as AIN1 ---------------------------------
GPIO_PORTE_DIR_R | &= ~0x04; | // make PE2 input
GPIO_PORTE_AFSEL_R | |= 0x04; | // enable alternate function on PE2
GPIO_PORTE_DEN_R | &= ~0x04; | // disable digital I/O on PE2
GPIO_PORTE_AMSEL_R | |= 0x04; | // enable analog functionality on PE2
}

Lab Baseline Schematic Guide: Rev 10-1-2021 | Page 10

// ----------------------------------------------------------------------------
// ---------------- | PORT F Initialization | --------------------------------
// ----------------------------------------------------------------------------//
// LaunchPad Pin Assignments
// PF4 = SW1
// PF3 = GREEN_LED
// PF2 = BLUE_LED
// PF1 = RED_LED
// PF0 = SW2

void Port_F_Init(void){

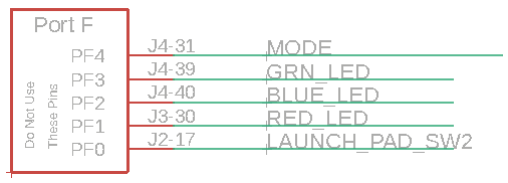
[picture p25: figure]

SYSCTL_RCGCGPIO_R | |= 0x00000020; | // activate clock for Port F
while((SYSCTL_PRGPIO_R & 0x20)==0){}; | // allow time for clock to stabilize
GPIO_PORTF_LOCK_R | = 0x4C4F434B; | // unlock GPIO Port F
GPIO_PORTF_CR_R | = 0x1F; | // allow changes to PF4-0
GPIO_PORTF_AMSEL_R | = 0x00; | // disable analog on PF
GPIO_PORTF_PCTL_R | = 0x00000000; | // PCTL GPIO on PF4-0
GPIO_PORTF_DIR_R | = 0x0E; | // PF4,PF0 in, PF3-1 out
GPIO_PORTF_AFSEL_R | = 0x00; | // disable alt function on PF7-0
GPIO_PORTF_PUR_R | = 0x11; | // enable pull-up on PF0 and PF4
GPIO_PORTF_DEN_R | = 0x1F; | // enable digital I/O on PF4-0
}

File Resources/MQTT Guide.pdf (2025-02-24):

## Contents

Lab 4 MQTT Writeup | 2

The Mobile App makes a change to thermostat temperature or

1

## Lab 4 MQTT Writeup

Key Aspects of MQTT

MQTT (Message Queuing Telemetry Transport), is a lightweight messaging protocol designed for low-bandwidth, high-latency, and unreliable networks. Developed in 1999 by IBM, MQTT is now a widely used open standard. MQTT is useful as it can:

- Organize data at the protocol level
- Cordinate actions between IOT devices
- Allow easy centralization of data to user-facing dashboards
- Send connected clients only the data they need
- Ensure a Quality Of Service (QOS) of data sent by clients

MQTT topology and the Publish/Subscribe Model:

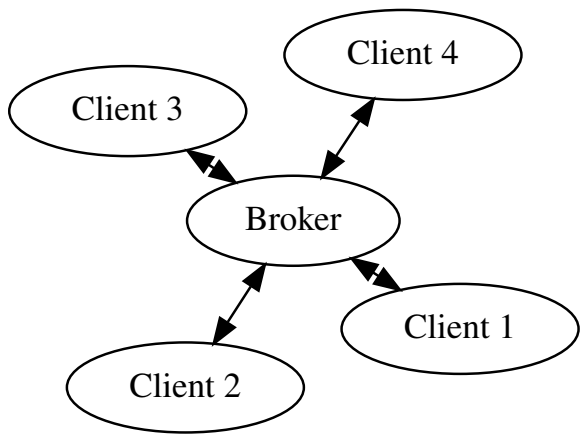
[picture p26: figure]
Broker; Client 1; Client 2; Client 3; Client 4

Figure 1: MQTT Client-Broker topology

MQTT includes ONLY broker to client/client to broker comunications. MQTT networks have one broker which facilitates comunication between many clients.

MQTT uses a Publish/Subscribe Model. In this model, data movement is controled by topics. Clients decide what data they recive, by deciding what topics they subscribe to. Clients can influence where data is sent by choosing what topic they attach to the data they publish. The messages sent and recived allways consist of a topic & data.

Although the broker is responsible for relaying data, it has no discresion to decide where data goes. The broker will relay a published message from any client to all clients that are subscribed to the topic of the message.

2

Topic Naming scheme:

An MQTT topic is a hierarchical string identifier that categorizes messages being published/subscribed to within the MQTT system. Topics are represented as strings and are organized hierarchically using forward slashes (‘/’). For example, a topic could be

"sensors/temperature/EER/floor1/embeddedlab."

or

"EER/floor1/embeddedlab/temperature"

How topics are defined are up to you. As long as they follow the typical hierarchical format.

Example of MQTT Communication

Here is an example of a typical MQTT communication between clients and how the broker routes it.

1. An MQTT client publishes a message to a specific topic on the MQTT broker.
2. The MQTT broker receives the published message and examines the topic.
3. The broker checks its subscription database to determine which MQTT client have subscribed to that topic.
4. The broker forwards the message to all subscribed clients
5. Subscribed MQTT clients receive the message and can take action based on its content.

Now lets imagine a scenario where we have a IoT setup in the EER. We have a three sensors which are their very own internet conected devices located in the EER. We have a temperature sensor in the 445L lab room, a thermostat located in the 319K room (let’s imagine the thermostat controls the A.C for the entirety of floor 1), and a faculty member has a mobile app that allows him to control the thermostat or see the readings from the sensors.

Here we have three clients:

- 445L Temperature Sensor
– Can read temperature in the 445L room
- 319K Lab Thermostat
– Connected via wire to the A.C, can control the A.C for the entirety of floor 1.
– Has its own temperature sensor that allows it to read the temperature in the room it is in (the 319K lab in this case)

3

– Has a temperature the thermostat can be set too. If the temperature in any of the rooms dip/rise above this temperature. The A.C is enabled to heat/cool
– Has a mode for the A.C. The A.C can either be off, set to cool, or set to heat.
– Can interface with external temperature sensors (such as the 445L temperature sensor)
– This closely resembles popular IoT thermostats such as the Nest or Ecobee
- Mobile App
– Allows you to control the thermostat (mode, set temperature)
– Read the temperature readings across all temperature sensors

All of these clients are connected to one central server (The MQTT Broker) to faciliate communication. This server could be for examples McDermott MQTT server in his office, or a public/cloud based MQTT Server.

Figure 2: Client-Broker setup of the Example

Now lets try to analyze what information each client provides, and what information each client would want from another client.

- 445L Temperature Sensor
– Reads the 445l lab room temperature, publishes it.
- 319K Lab Thermostat
– Reads the temperature in the 319K room, can act on this reading (enable the A.C for floor 1). Can also publish it (for the mobile app) – Is interested in the temperature in the 445L room, can act on this reading (enable the A.C for floor 1)
– Has a temperature that can be set to enable cooling/heat (acting on this data) It can publish this temperature (for the mobile app), and it can also have this changed externally (from the mobile app)
– Has a A.C mode (off/cool/heat). It acts on this mode (enable the A.C for cool/hot if the outside temperature changes). It can publish this data (so the mobile app knows the current A.C mode), it can also have this changed externally (from the mobile app)
- Mobile App
– Can set the A.C mode from the mobile app. Changes to this can be made from app or thermostate

4

– Can set the thermostat temperature. Changes can be made from app or thermostat.
– Can read all temperature sensor readings.

From this lets define the following topics, and these publishers and subscribers

- /EER/floor1/445Lab/temperature
- Publishers:
- 445L Temperature Sensor
- Subscribers:
- 319K Thermostat
- Mobile App
- /EER/floor1/319KLab/temperature
- Publishers:
- 319K Thermostat
- Subscribers:
- Mobile App
- /EER/floor1/thermostat/set_temp
- Publishers:
- 319K Thermostat
- Mobile App
- Subscribers:
- 319K Thermostat
- Mobile App
- /EER/floor1/thermostat/mode
- Publishers:
- 319K Thermostat
- Mobile App
- Subscribers:
- 319K Thermostat
- Mobile App

The scenario where 445L Lab Temp Changes

If the 445L lab room temperature changes. The sensor publishes to its topic its payload.

5

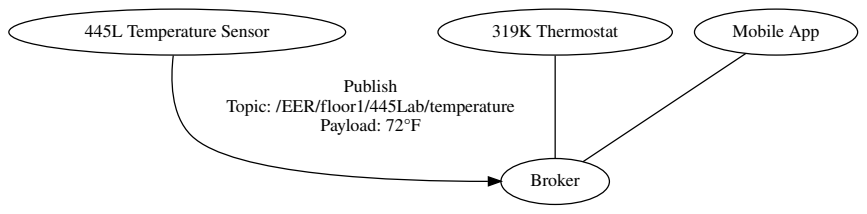
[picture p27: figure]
Broker; 445L Temperature Sensor; Publish Topic: /EER/floor1/445Lab/temperature Payload: 72°F; 319K Thermostat; Mobile App

Figure 3: 445L Temperature Sensor publishes change

The thermostat, and mobile app are subscribers and therefore notified.

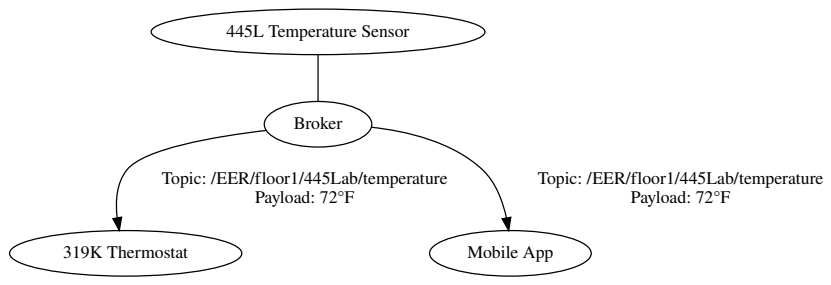
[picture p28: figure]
Broker; 319K Thermostat; Topic: /EER/floor1/445Lab/temperature Payload: 72°F; Mobile App; 445L Temperature Sensor

Figure 4: Subscribers are notified

The thermostat could act on this change. For example if the temperature 72°F exceeds/below the set temperature, it could enable the A.C. The mobile app also now has up-to date sensor reading.

The scenario where 319K Lab temp changes.

The thermostat has it’s own temperature sensor measuring the temperature of the 319K room. The thermostat can act this temperature (enable the A.C for example). But the mobile app also wants to be up-to date regarding all temperature readings.

6

Figure 5: Thermostat Temperature Sensor publishes change

The mobile app is subscribed to the all temperature readings, including the

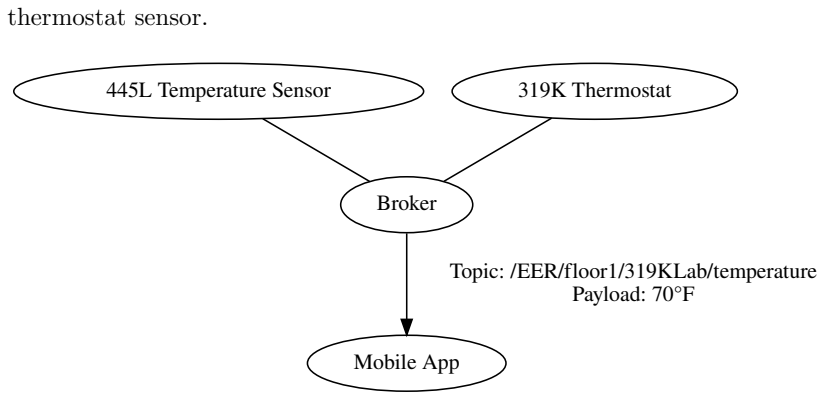
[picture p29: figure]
thermostat sensor.; Broker; Mobile App; Topic: /EER/floor1/319KLab/temperature Payload: 70°F; 445L Temperature Sensor; 319K Thermostat

Figure 6: Subscribers are notified

Thermostat has a change in set temperature or mode.

If you were to change the set temperature on the thermostat.

Figure 7: Thermostat Set Temp changes

The mobile app will be notified.

7

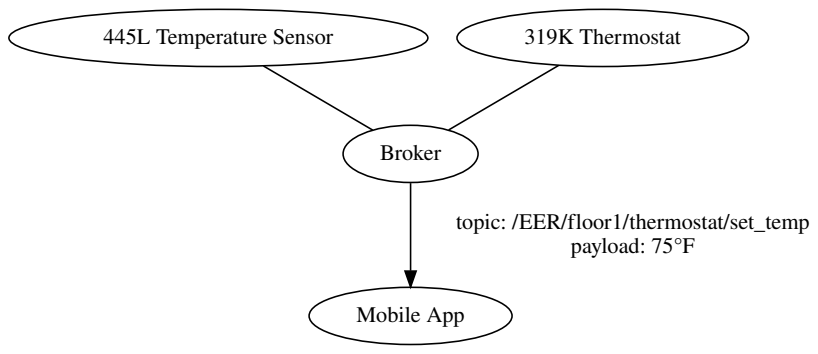
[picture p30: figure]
Broker; Mobile App; topic: /EER/floor1/thermostat/set_temp payload: 75°F; 445L Temperature Sensor; 319K Thermostat

Figure 8: Subscribers are notified

Similarily if you were to change the mode from “heat” to “cool” on the thermostat

Figure 9: Thermostat Set Temp changes

The mobile app will be notified.

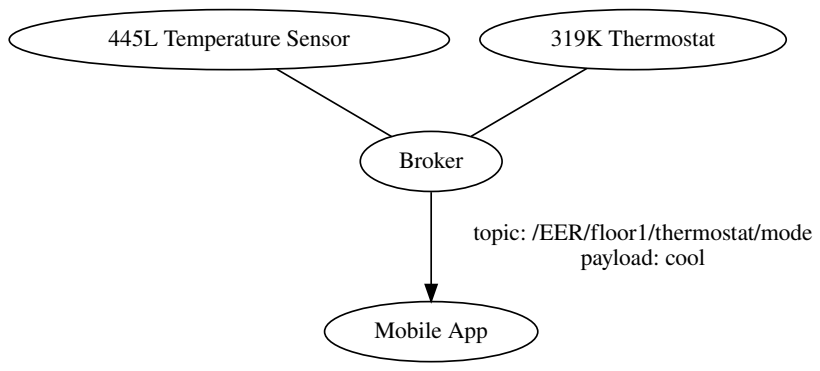
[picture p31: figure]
Broker; Mobile App; topic: /EER/floor1/thermostat/mode payload: cool; 445L Temperature Sensor; 319K Thermostat

Figure 10: Subscribers are notified

8

The Mobile App makes a change to thermostat temperature or mode

If we want to change the set temperature of the thermostat from the mobile app.

Figure 11: Thermostat Set Temp changes from Mobile App

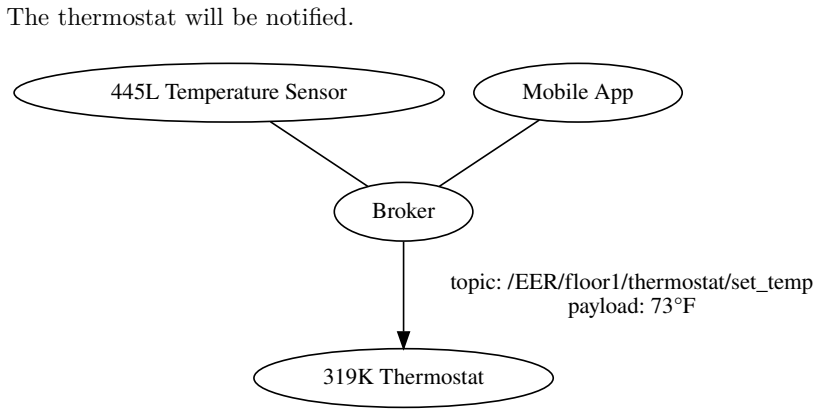
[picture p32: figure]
The thermostat will be notified.; Broker; 319K Thermostat; topic: /EER/floor1/thermostat/set_temp payload: 73°F; 445L Temperature Sensor; Mobile App

Figure 12: Subscribers are notified

Similarily if we want to turn off the A.C from the mobile app.

Figure 13: Thermostat Mode changes from Mobile App

The thermostat will be notified.

9

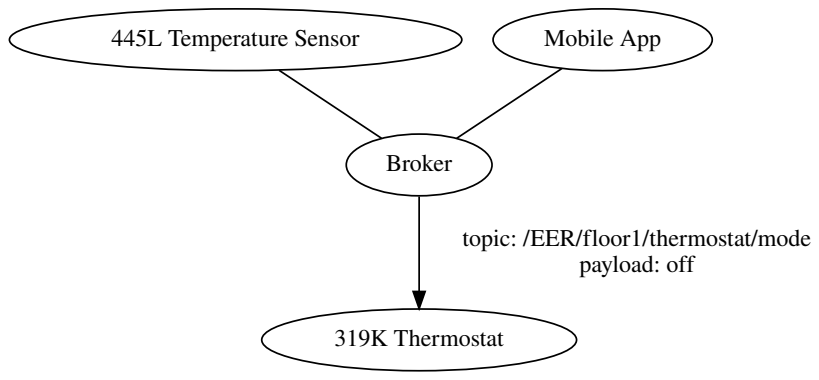
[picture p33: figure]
Broker; 319K Thermostat; topic: /EER/floor1/thermostat/mode payload: off; 445L Temperature Sensor; Mobile App

Figure 14: Subscribers are notified

How to approach Lab 4

From the perspective of the lab we have two clients:

- Your Alarm Clock
- The web dashboard

and a broker (the free broker service we are using called emqx.io).

From the perspective of the free broker service however, it has your alarm clock and web dashboard as a client. As well as the alarm clock and web dashboard of everyone else in the class (and anyone else using the service). So when you define your topics make sure the topic string is unique. For example if everyone used the same topic, lets say “alarm/current_time”, you would be able to change the time of everyones alarm clock. So to make unique topic names, your topic should start with your eid, ex. “eid123/alarm/current_time”.

Here is how we reccomend approaching this lab to avoid stress and headaches. First things first, don’t try integrating lab3 right away, instead get topics working.

Using the starter code, do the following.

1. ESP Bring up, the ESP8266 should be able to connect to a network and to the broker. This should be done in prep. Come to your TA’s if you were unable to do this.
2. Define your topics, and the subscriber/publisher relationships.
3. Have both of you open the web dashboard. Have one person subscribe to a topic, and have the other publish to the topic. The subscriber should be able to receive a message when this happens.
4. Modify your TM4C starter code so you can communicate with the ESP. The TM4C communicates with the ESP over UART. You can observe what

10 is being sent to the ESP via USB-Serial between your PC and the TM4C using a serial terminal.
5. Test, can you publish to a topic from the TM4C, do you see this change reflected on the web dashboard?
6. Test, can you publish to a topic from the web dashboard, do you see this change reflected on the TM4C?
7. Now that you can publish/subscribe to topics. Now integrate your Lab 3 Code.

If you need any help, please email us or come to our office hours.

11

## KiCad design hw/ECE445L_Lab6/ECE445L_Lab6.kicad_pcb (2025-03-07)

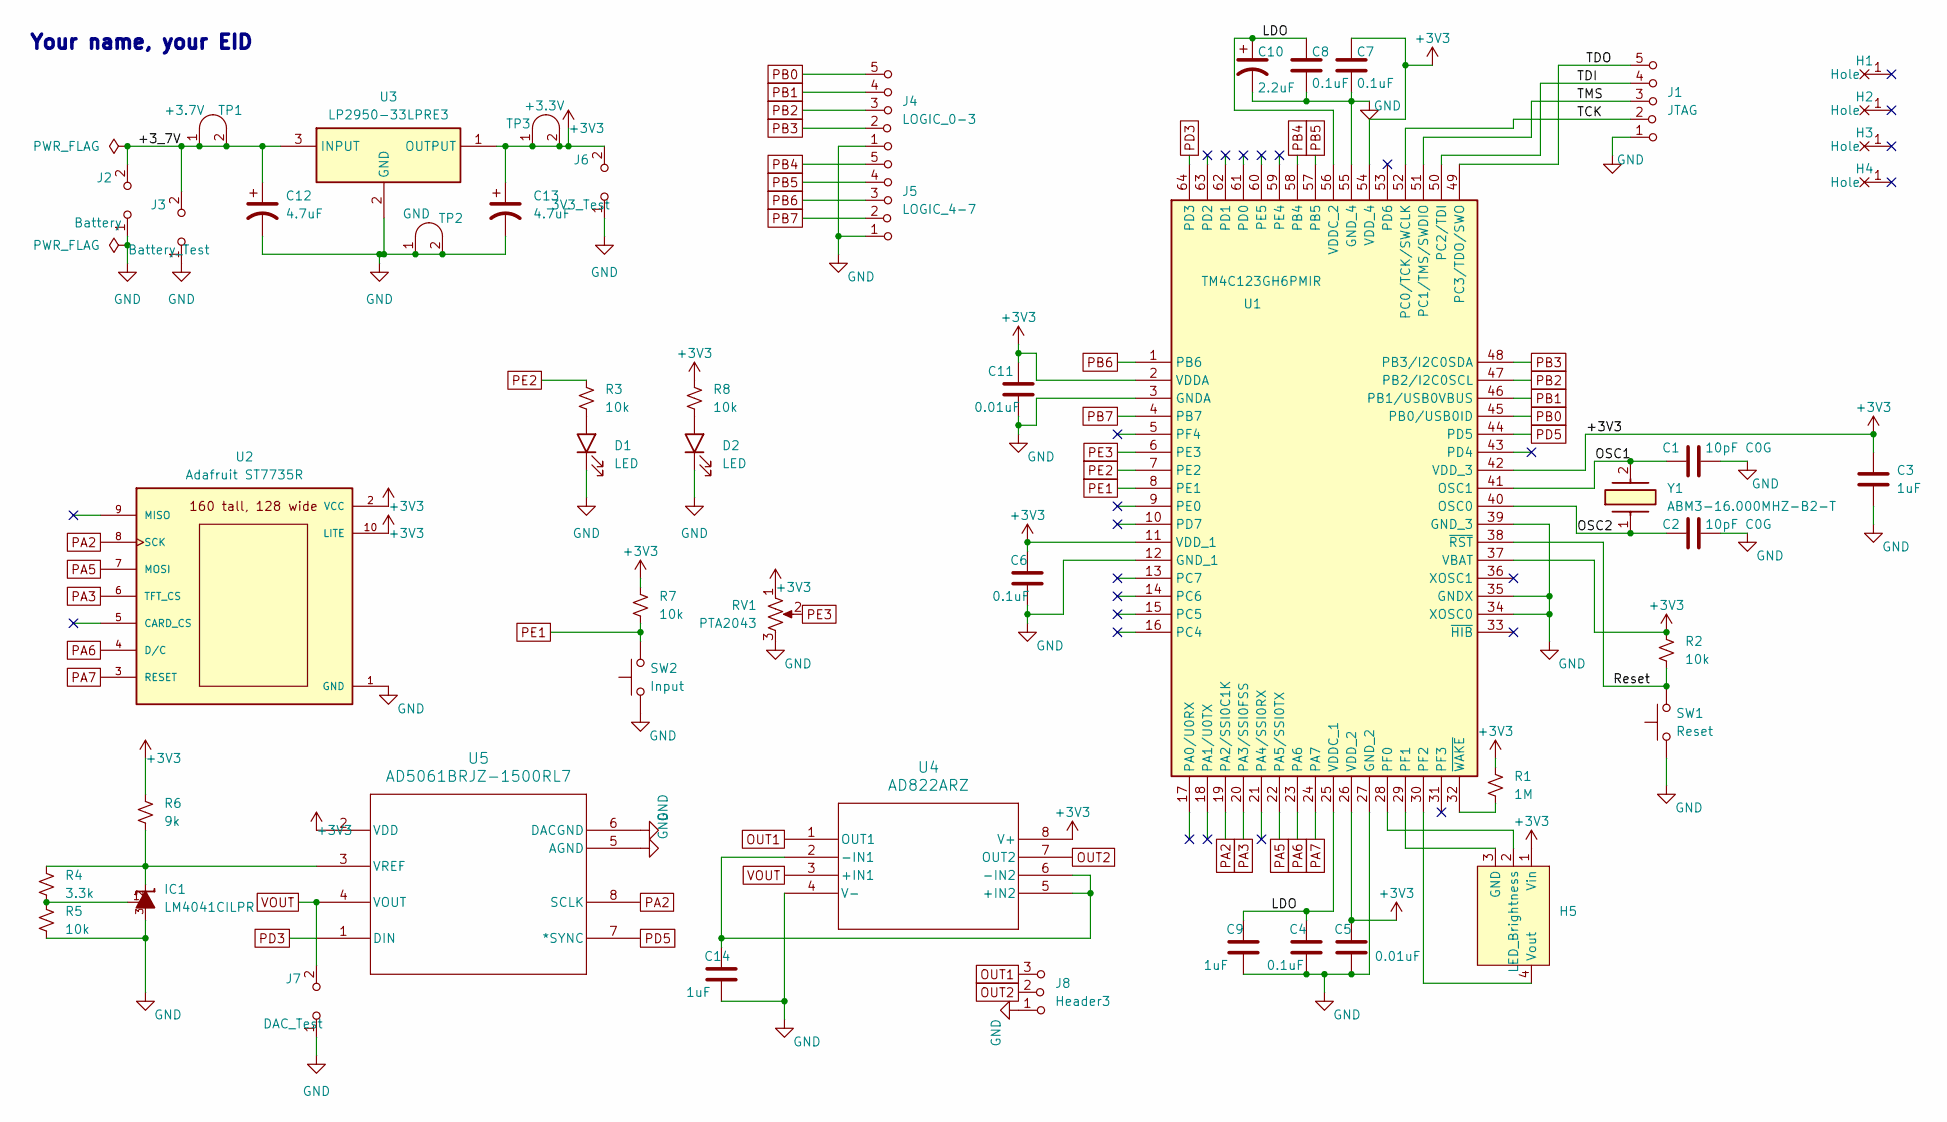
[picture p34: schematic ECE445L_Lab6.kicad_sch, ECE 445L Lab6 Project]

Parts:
C1, C2: 10pF C0G; C_Axial_200mil
C3, C9, C14: 1uF; C_Axial_200mil
C4, C6, C7, C8: 0.1uF; C_Axial_200mil
C5, C11: 0.01uF; C_Axial_200mil
C10: 2.2uF; CP_Radial_Tantal200mil
C12, C13: 4.7uF; CP_Radial_Tantal200mil
D1, D2: LED; LED_D5.0mm
H1, H2, H3, H4: MountingHole_4_40
H5: HEARTBEAT
IC1: LM4041CILPR; ti_LM4041CILPR
J1: JTAG; PinHeader_1x05_P2.54mm_Vertical
J2: Battery; PinHeader_1x02_P2.54mm_Vertical
J3: Battery_Test; PinHeader_1x02_P2.54mm_Vertical
J4: LOGIC_0-3; PinHeader_1x05_P2.54mm_Vertical
J5: LOGIC_4-7; PinHeader_1x05_P2.54mm_Vertical
J6: 3V3_Test; PinHeader_1x02_P2.54mm_Vertical
J7: DAC_Test; PinHeader_1x02_P2.54mm_Vertical
J8: Header3; PinHeader_1x03_P2.54mm_Vertical
R1: 1M; R_Axial_DIN0204_L3.6mm_D1.6mm_P7.62mm_Horizontal
R2, R3, R5, R7, R8: 10k; R_Axial_DIN0204_L3.6mm_D1.6mm_P7.62mm_Horizontal
R4: 3.3k; R_Axial_DIN0204_L3.6mm_D1.6mm_P7.62mm_Horizontal
R6: 9k; R_Axial_DIN0204_L3.6mm_D1.6mm_P7.62mm_Horizontal
RV1: PTA2043; PTA2043pot
SW1: Reset; SW_PUSH_6mm
SW2: Input; SW_PUSH_6mm
TP1: +3.7V; Testpoint_1x02_P2.54mm
TP2: GND; Testpoint_1x02_P2.54mm
TP3: +3.3V; Testpoint_1x02_P2.54mm
U1: TM4C123GH6PMIR; QFP50P1200X1200X160-64N; Mouser Part Number 595-TM4C123GH6PMIR
U2: Adafruit ST7735R; adafruit_st7735r2
U3: LP2950-33LPRE3; TL431CLPM; Mouser Part Number 595-LP2950-33LPRE3
U4: AD822ARZ; R_8_ADI
U5: AD5061BRJZ-1500RL7; RJ_8_ADI
Y1: ABM3-16.000MHZ-B2-T; ABM3; Mouser Part Number 815-ABM3-16-B2-T

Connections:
+3V3: C3.1, C5.1, C6.1, C7.1, C11.1, C13.1, H5.1 (Vin), J6.2 (B), R1.1, R2.1, R6.1, R7.1, R8.1, RV1.1, TP3.1 (A), TP3.2 (B), U1.2 (VDDA), U1.11 (VDD_1), U1.26 (VDD_2), U1.37 (VBAT), U1.42 (VDD_3), U1.54 (VDD_4), U2.2 (VCC), U2.10 (LITE), U3.1 (OUTPUT), U4.8 (V+), U5.2 (VDD)
/+3_7V: C12.1, J2.2 (B), J3.2 (B), TP1.1 (A), TP1.2 (B), U3.3 (INPUT)
/LDO: C4.1, C8.1, C9.1, C10.1, U1.25 (VDDC_1), U1.56 (VDDC_2)
/OSC1: C1.1, U1.41 (OSC1), Y1.2
/OSC2: C2.1, U1.40 (OSC0), Y1.1
/Reset: R2.2, SW1.2, U1.38 (~RST)
/TCK: J1.2 (B), U1.52 (PC0/TCK/SWCLK)
/TDI: J1.4 (C), U1.50 (PC2/TDI)
/TDO: J1.5 (C), U1.49 (PC3/TDO/SWO)
/TMS: J1.3 (C), U1.51 (PC1/TMS/SWDIO)
GND: C1.2, C2.2, C3.2, C4.2, C5.2, C6.2, C7.2, C8.2, C9.2, C10.2, C11.2, C12.2, C13.2, C14.2, D1.1 (K), D2.1 (K), IC1.3, J1.1 (A), J2.1 (A), J3.1 (A), J4.1 (A), J5.1 (A), J6.1 (A), J7.1 (A), J8.1 (A), R5.2, RV1.3, SW1.1, SW2.1, TP2.1 (A), TP2.2 (B), U1.3 (GNDA), U1.12 (GND_1), U1.27 (GND_2), U1.34 (XOSC0), U1.35 (GNDX), U1.39 (GND_3), U1.55 (GND_4), U2.1 (GND), U3.2 (GND), U4.4 (V-), U5.5 (AGND), U5.6 (DACGND)
unnamed: D1.2 (A), R3.2
unnamed: D2.2 (A), R8.2
unnamed: H5.3 (GND), U1.29 (PF1)
unnamed: H5.2 (LED_Brightness), U1.28 (PF0)
unnamed: H5.4 (Vout), U1.30 (PF2)
unnamed: IC1.1, R4.2, R5.1
unnamed: R1.2, U1.32 (~WAKE)
unnamed: C14.1, U4.2 (-IN1), U4.5 (+IN2), U4.6 (-IN2)
unnamed: IC1.2, R4.1, R6.2, U5.3 (VREF)
OUT1: J8.3 (C), U4.1 (OUT1)
OUT2: J8.2 (B), U4.7 (OUT2)
PA2: U1.19 (PA2/SSI0C1K), U2.8 (SCK), U5.8 (SCLK)
PA3: U1.20 (PA3/SSI0FSS), U2.6 (TFT_CS)
PA5: U1.22 (PA5/SSI0TX), U2.7 (MOSI)
PA6: U1.23 (PA6), U2.4 (D/C)
PA7: U1.24 (PA7), U2.3 (RESET)
PB0: J4.5 (C), U1.45 (PB0/USB0ID)
PB1: J4.4 (C), U1.46 (PB1/USB0VBUS)
PB2: J4.3 (C), U1.47 (PB2/I2C0SCL)
PB3: J4.2 (B), U1.48 (PB3/I2C0SDA)
PB4: J5.5 (C), U1.58 (PB4)
PB5: J5.4 (C), U1.57 (PB5)
PB6: J5.3 (C), U1.1 (PB6)
PB7: J5.2 (B), U1.4 (PB7)
PD3: U1.64 (PD3), U5.1 (DIN)
PD5: U1.44 (PD5), U5.7 (*SYNC)
PE1: R7.2, SW2.2, U1.8 (PE1)
PE2: R3.1, U1.7 (PE2)
PE3: RV1.2, U1.6 (PE3)
VOUT: J7.2 (B), U4.3 (+IN1), U5.4 (VOUT)

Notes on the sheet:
Your name, your EID

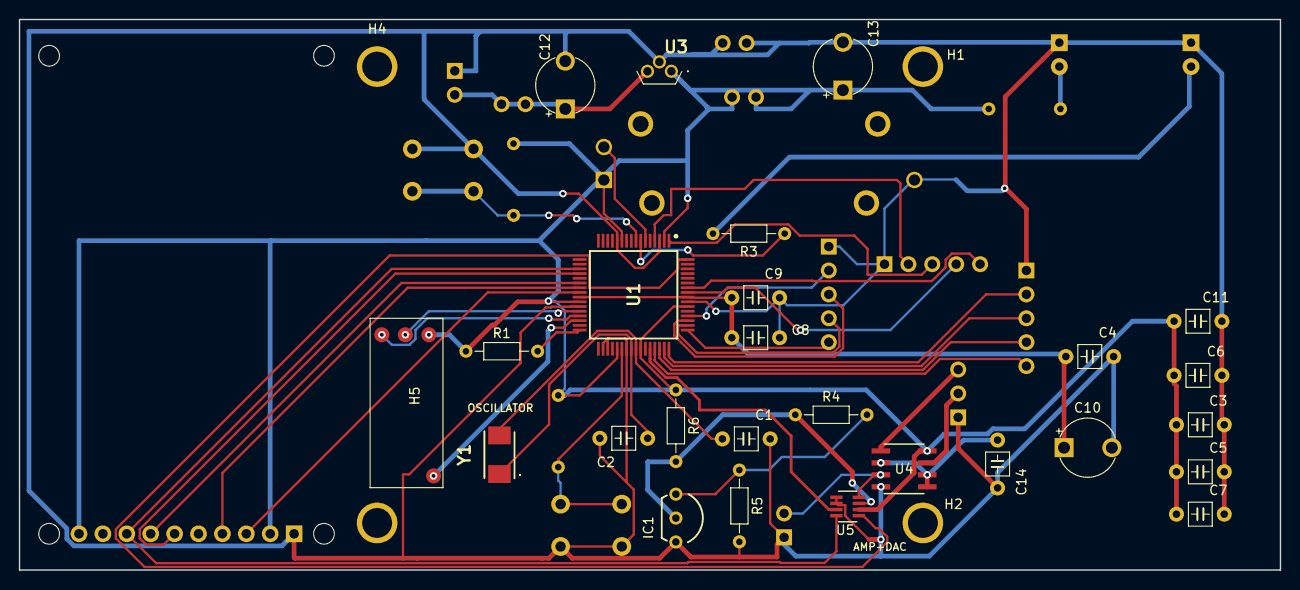
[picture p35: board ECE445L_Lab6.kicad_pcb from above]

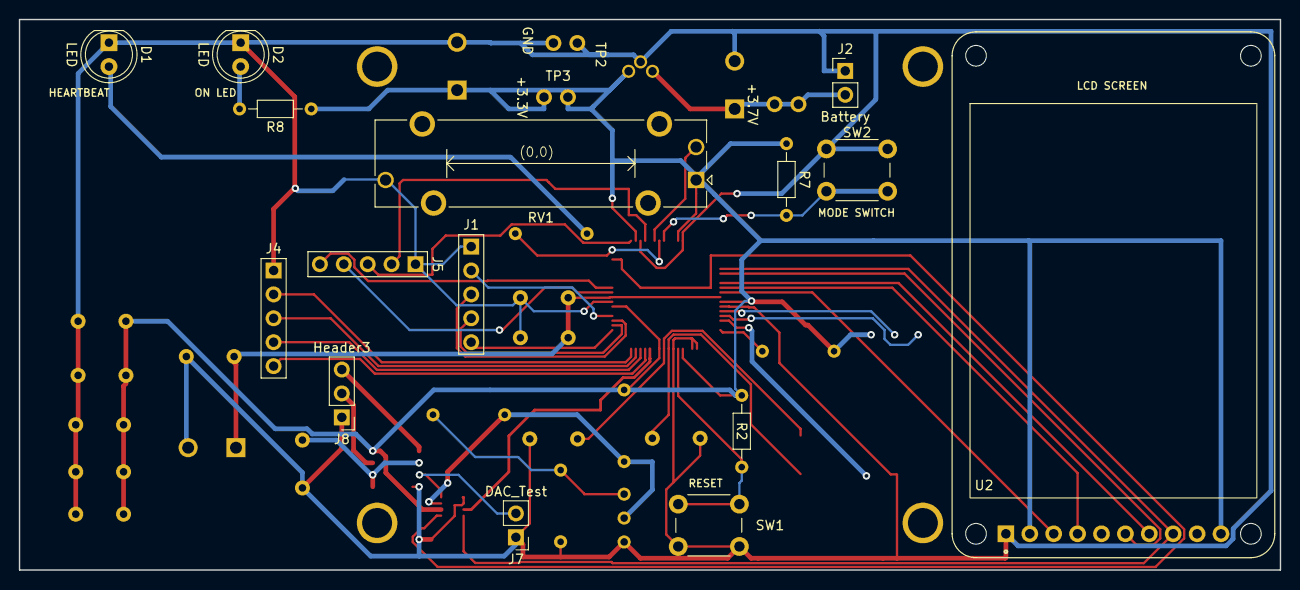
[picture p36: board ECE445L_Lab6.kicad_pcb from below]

Board: 2 copper layers, 134.0 x 58.5 mm, 48 parts (18 on the bottom side), 41 nets.

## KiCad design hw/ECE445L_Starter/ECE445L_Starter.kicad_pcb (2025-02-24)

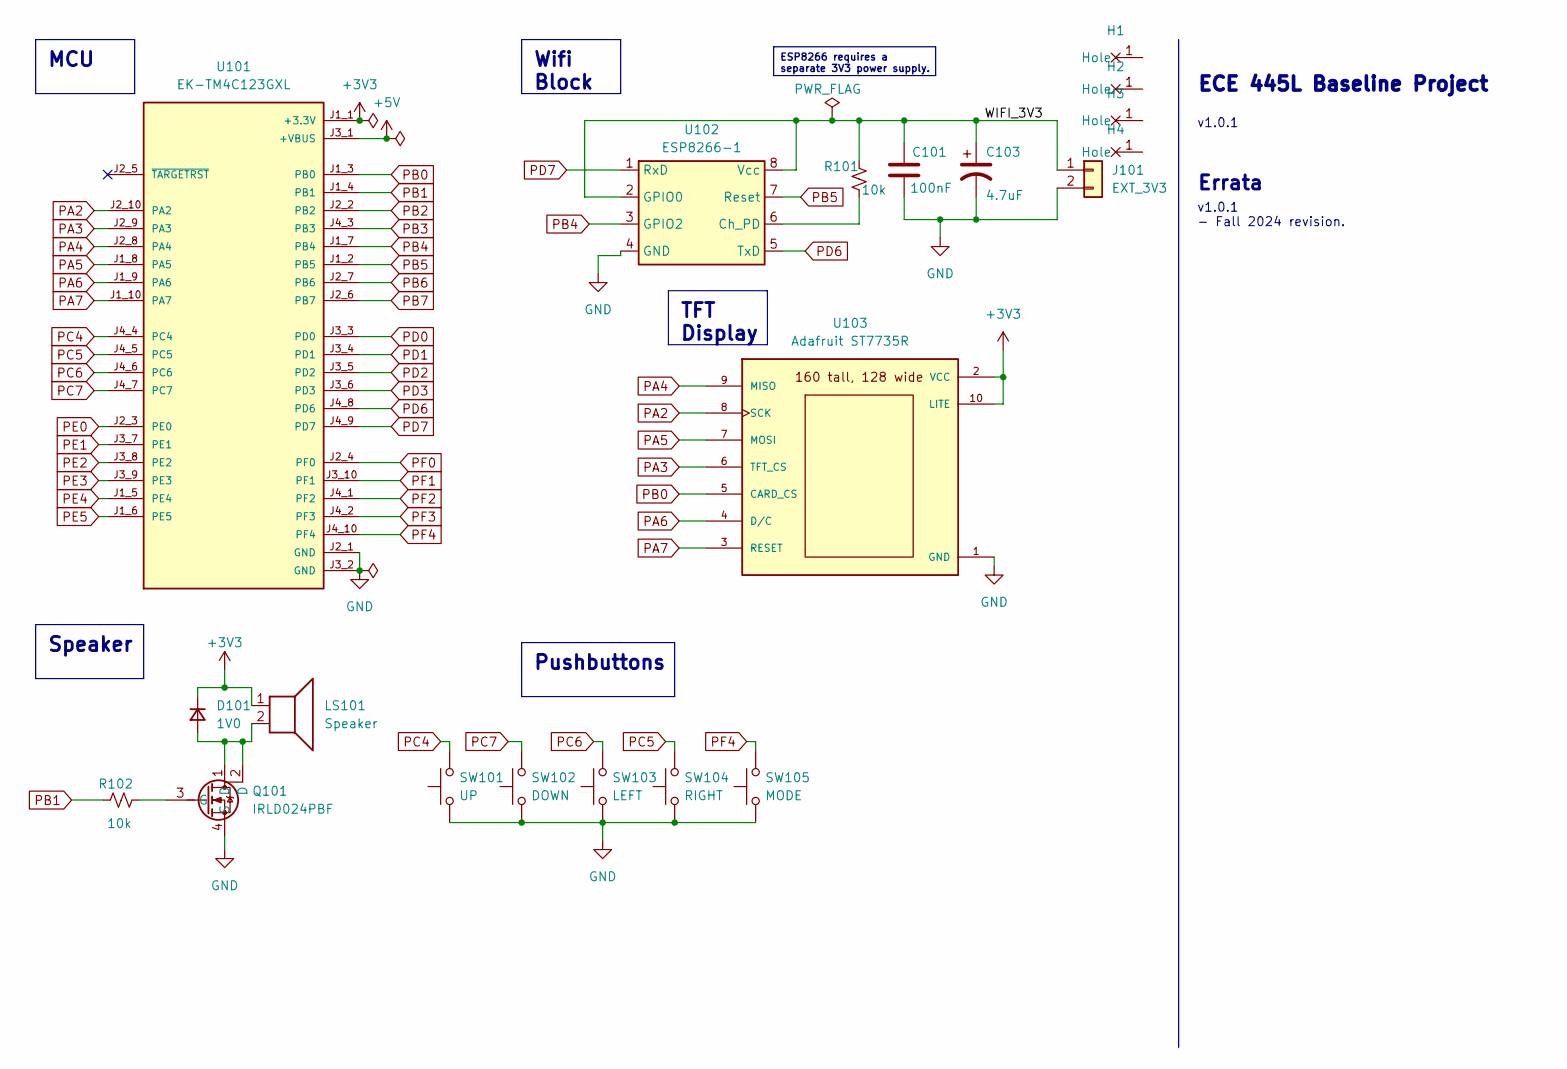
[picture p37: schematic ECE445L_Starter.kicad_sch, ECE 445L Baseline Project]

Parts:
C101: 100nF; C_Axial_200mil
C103: 4.7uF; CP_Radial_Tantal200mil
D101: 1V0; D_5W_P12.70mm_Horizontal
H1, H2, H3, H4: MountingHole_4_40
J101: EXT_3V3; Samtec_HPM-02-01-x-S_Straight_1x02_Pitch5.08mm
LS101: Speaker; PinHeader_1x02_P2.54mm_Vertical
Q101: IRLD024PBF; DIP920W60P254L490H457Q4N; Mouser Part Number 844-IRLD024PBF
R101, R102: 10k; R_Axial_DIN0204_L3.6mm_D1.6mm_P7.62mm_Horizontal
SW101: UP; SW_PUSH_6mm
SW102: DOWN; SW_PUSH_6mm
SW103: LEFT; SW_PUSH_6mm
SW104: RIGHT; SW_PUSH_6mm
SW105: MODE; SW_PUSH_6mm
U101: EK-TM4C123GXL; ti_EKTM4C123GXL
U102: ESP8266-1; PinHeader_2x04_P2.54mm_Vertical
U103: Adafruit ST7735R; adafruit_st7735r2

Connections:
+3V3: D101.1 (K), LS101.1, U101.J1_1 (+3.3V), U103.2 (VCC), U103.10 (LITE)
+5V: U101.J3_1 (+VBUS)
/WIFI_3V3: C101.1, C103.1, J101.1, R101.1, U102.2 (GPIO0), U102.8 (Vcc)
GND: C101.2, C103.2, J101.2, Q101.4 (S), SW101.1, SW102.1, SW103.1, SW104.1, SW105.1, U101.J2_1 (GND), U101.J3_2 (GND), U102.4 (GND), U103.1 (GND)
unnamed: D101.2 (A), LS101.2, Q101.1 (D), Q101.2 (D)
unnamed: Q101.3 (G), R102.2
unnamed: R101.2, U102.6 (Ch_PD)
PA2: U101.J2_10 (PA2), U103.8 (SCK)
PA3: U101.J2_9 (PA3), U103.6 (TFT_CS)
PA4: U101.J2_8 (PA4), U103.9 (MISO)
PA5: U101.J1_8 (PA5), U103.7 (MOSI)
PA6: U101.J1_9 (PA6), U103.4 (D/C)
PA7: U101.J1_10 (PA7), U103.3 (RESET)
PB0: U101.J1_3 (PB0), U103.5 (CARD_CS)
PB1: R102.1, U101.J1_4 (PB1)
PB2: U101.J2_2 (PB2)
PB3: U101.J4_3 (PB3)
PB4: U101.J1_7 (PB4), U102.3 (GPIO2)
PB5: U101.J1_2 (PB5), U102.7 (Reset)
PB6: U101.J2_7 (PB6)
PB7: U101.J2_6 (PB7)
PC4: SW101.2, U101.J4_4 (PC4)
PC5: SW104.2, U101.J4_5 (PC5)
PC6: SW103.2, U101.J4_6 (PC6)
PC7: SW102.2, U101.J4_7 (PC7)
PD0: U101.J3_3 (PD0)
PD1: U101.J3_4 (PD1)
PD2: U101.J3_5 (PD2)
PD3: U101.J3_6 (PD3)
PD6: U101.J4_8 (PD6), U102.5 (TxD)
PD7: U101.J4_9 (PD7), U102.1 (RxD)
PE0: U101.J2_3 (PE0)
PE1: U101.J3_7 (PE1)
PE2: U101.J3_8 (PE2)
PE3: U101.J3_9 (PE3)
PE4: U101.J1_5 (PE4)
PE5: U101.J1_6 (PE5)
PF0: U101.J2_4 (PF0)
PF1: U101.J3_10 (PF1)
PF2: U101.J4_1 (PF2)
PF3: U101.J4_2 (PF3)
PF4: SW105.2, U101.J4_10 (PF4)

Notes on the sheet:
MCU
ESP8266 requires a separate 3V3 power supply.
Speaker
Pushbuttons
TFT Display
Wifi Block
v1.0.1 - Fall 2024 revision.
ECE 445L Baseline Project
v1.0.1
Errata

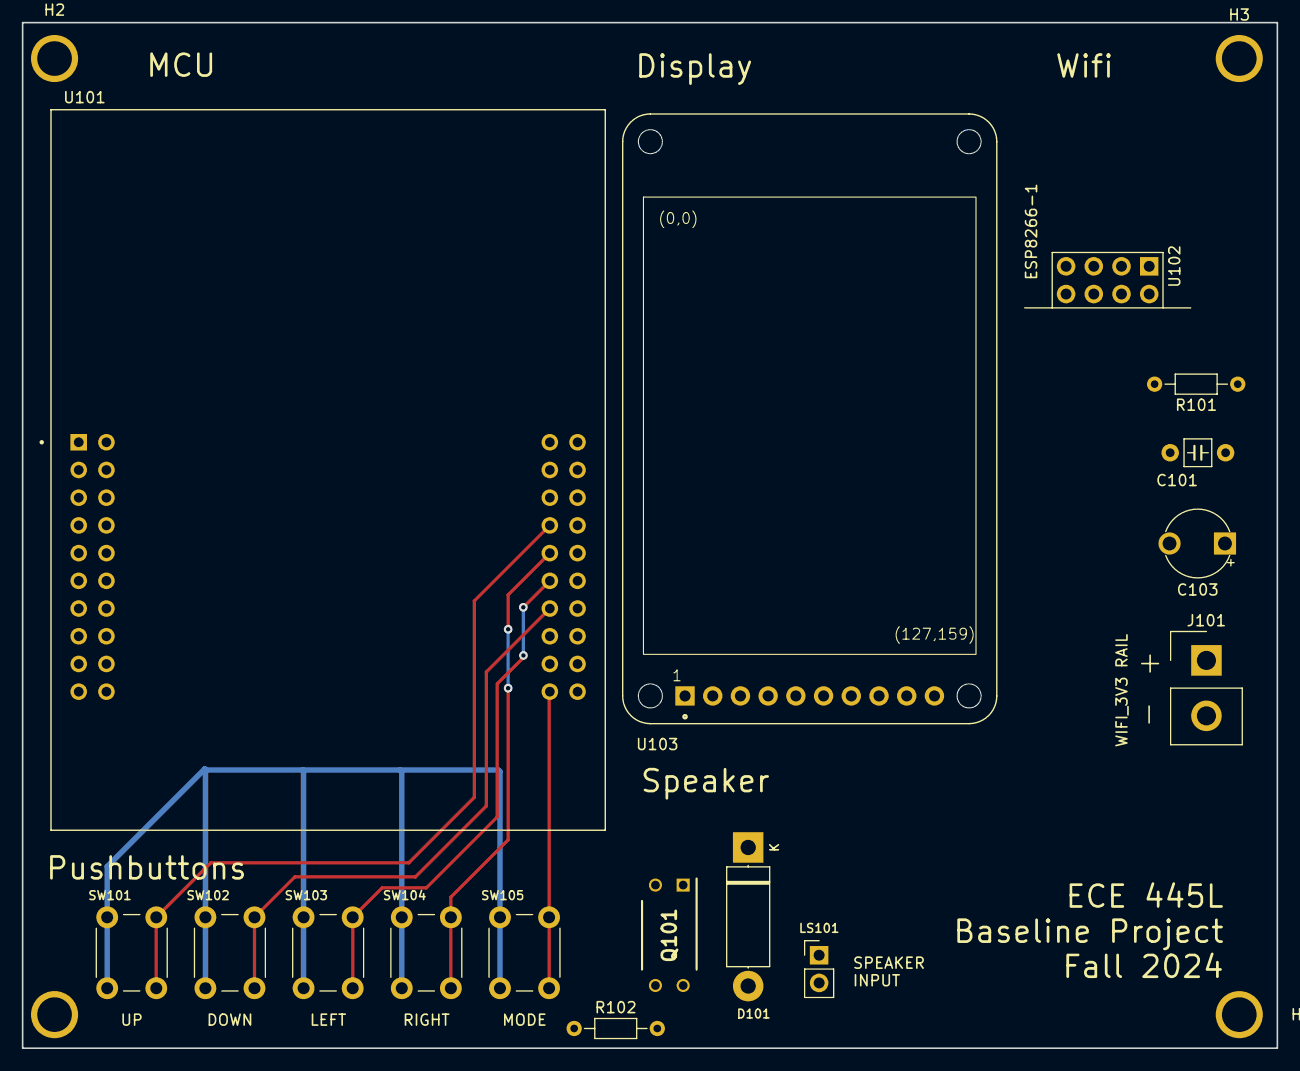
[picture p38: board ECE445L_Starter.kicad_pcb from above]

Board: 2 copper layers, 115.0 x 94.0 mm, 20 parts (0 on the bottom side), 23 nets.

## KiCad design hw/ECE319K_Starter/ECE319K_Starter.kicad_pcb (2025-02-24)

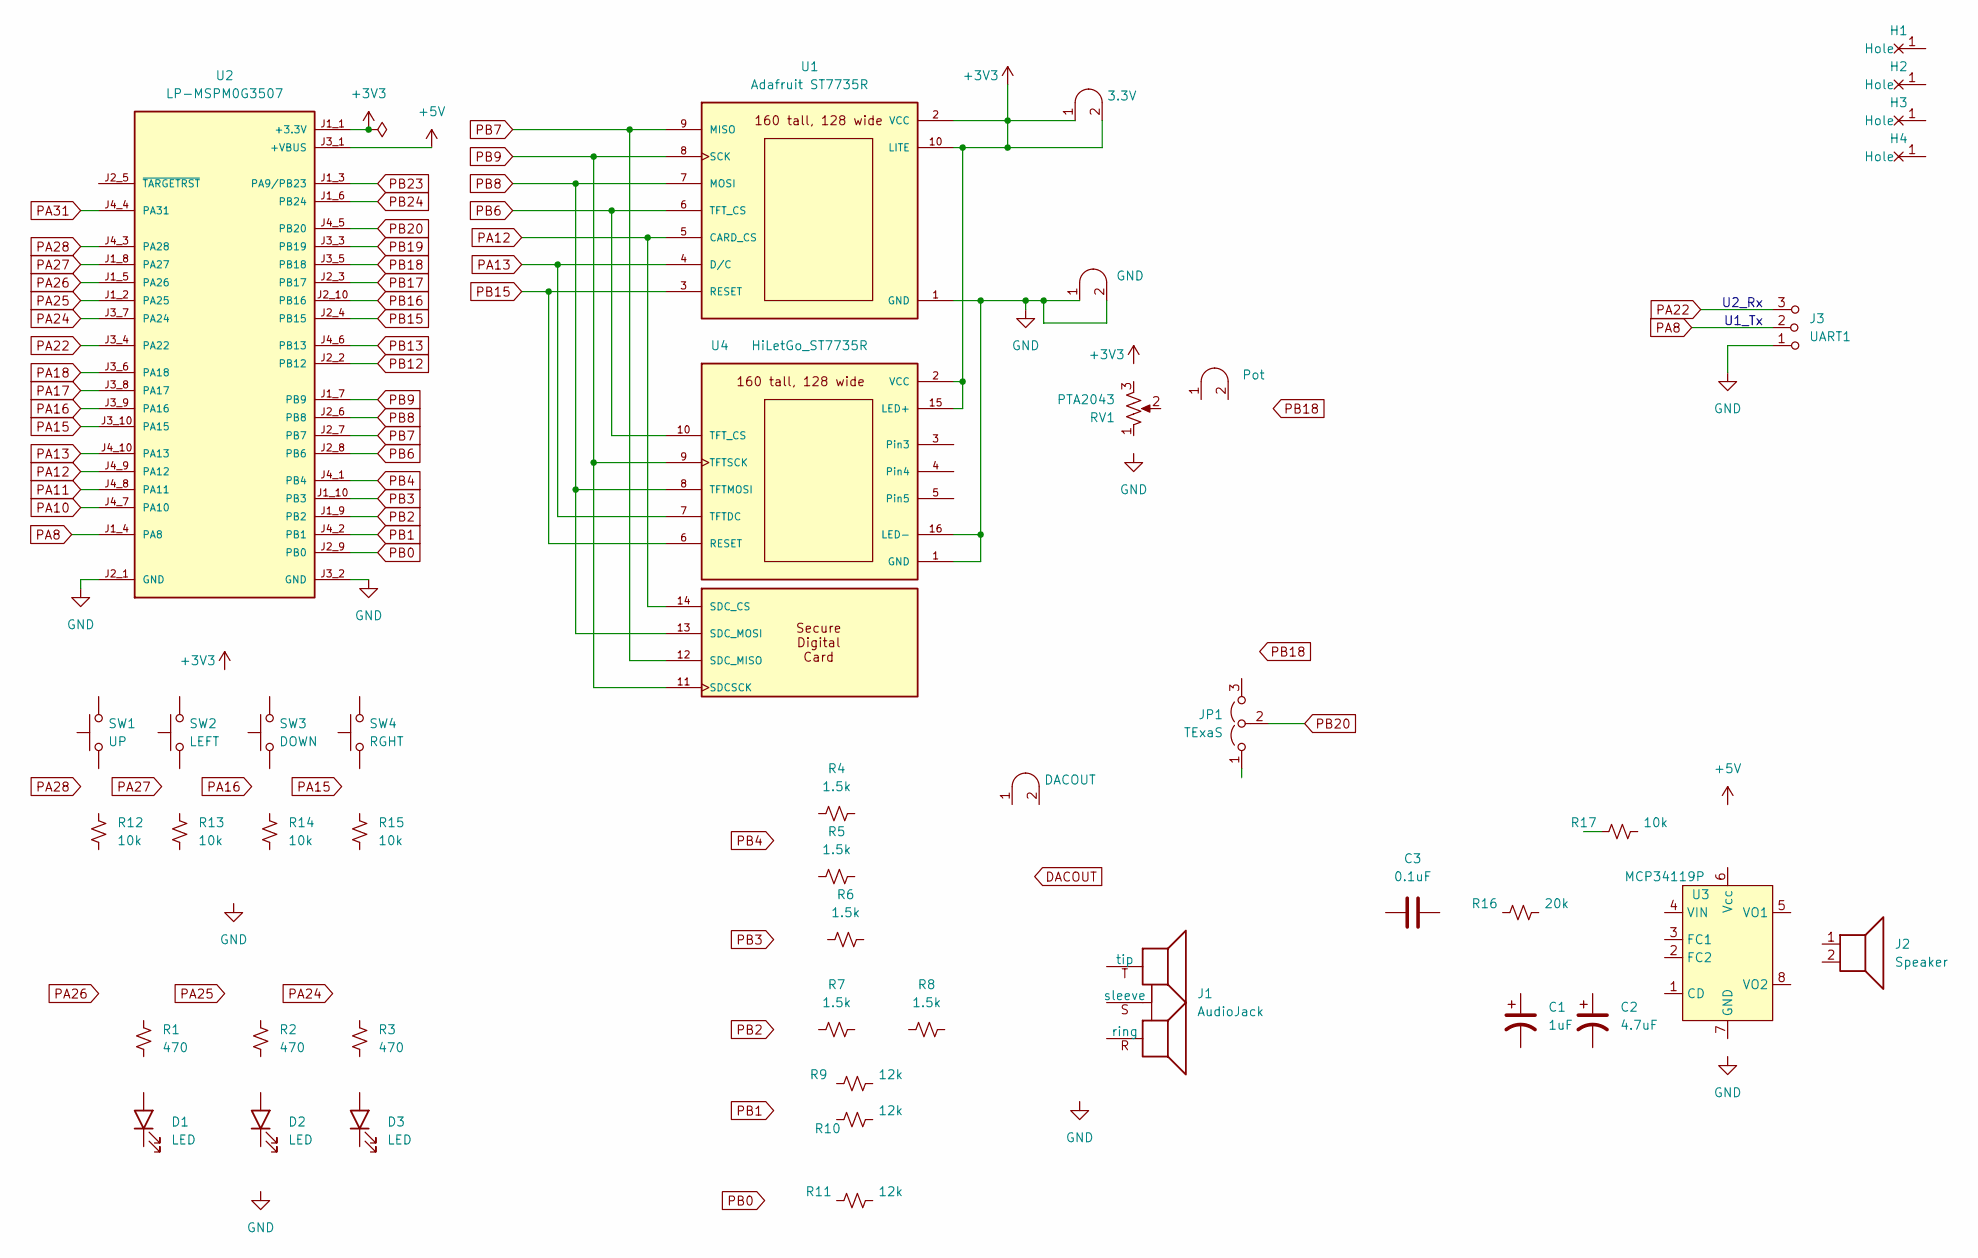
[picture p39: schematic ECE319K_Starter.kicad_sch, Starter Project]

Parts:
C1: 1uF; CP_Radial_Tantal200mil
C2: 4.7uF; CP_Radial_Tantal200mil
C3: 0.1uF; C_Axial_200mil
D1, D2, D3: LED; LED_D5.0mm
H1, H2, H3, H4: MountingHole_4_40
J1: AudioJack; Jack_3.5mm_CUI_SJ1-3523N_Horizontal
J2: Speaker; PinHeader_1x02_P2.54mm_Vertical
J3: UART1; PinHeader_1x03_P2.54mm_Vertical
J4: Pot; Testpoint_1x02_P2.54mm
J6: GND; Testpoint_1x02_P2.54mm
J7: DACOUT; Testpoint_1x02_P2.54mm
JP1: TExaS; PinHeader_1x03_P2.54mm_Vertical
R1, R2, R3: 470; R_Axial_DIN0204_L3.6mm_D1.6mm_P7.62mm_Horizontal
R4, R5, R6, R7, R8: 1.5k; R_Axial_DIN0204_L3.6mm_D1.6mm_P7.62mm_Horizontal
R9, R10, R11: 12k; R_Axial_DIN0204_L3.6mm_D1.6mm_P7.62mm_Horizontal
R12, R13, R14, R15, R17: 10k; R_Axial_DIN0204_L3.6mm_D1.6mm_P7.62mm_Horizontal
R16: 20k; R_Axial_DIN0204_L3.6mm_D1.6mm_P7.62mm_Horizontal
RV1: PTA2043; PTA2043pot
SW1: UP; SW_PUSH_6mm
SW2: LEFT; SW_PUSH_6mm
SW3: DOWN; SW_PUSH_6mm
SW4: RGHT; SW_PUSH_6mm
TP1: 3.3V; Testpoint_1x02_P2.54mm
U1: Adafruit ST7735R; adafruit_st7735r2
U2: LP-MSPM0G3507; ti_LP_MSPM0G3507
U3: MCP34119P; DIP-8_W7.62mm_LongPads
U4: HiLetGo_ST7735R; hiletgo_st7735r

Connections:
+3V3: TP1.1 (A), TP1.2 (B), U1.2 (VCC), U1.10 (LITE), U2.J1_1 (+3.3V), U4.2 (VCC), U4.15 (LED+)
+5V: U2.J3_1 (+VBUS)
GND: J3.1 (A), J6.1 (A), J6.2 (B), U1.1 (GND), U2.J2_1 (GND), U2.J3_2 (GND), U4.1 (GND), U4.16 (LED-)
PA8: J3.2 (B), U2.J1_4 (PA8)
PA10: U2.J4_7 (PA10)
PA11: U2.J4_8 (PA11)
PA12: U1.5 (CARD_CS), U2.J4_9 (PA12), U4.14 (SDC_CS)
PA13: U1.4 (D/C), U2.J4_10 (PA13), U4.7 (TFTDC)
PA15: U2.J3_10 (PA15)
PA16: U2.J3_9 (PA16)
PA17: U2.J3_8 (PA17)
PA18: U2.J3_6 (PA18)
PA22: J3.3 (C), U2.J3_4 (PA22)
PA24: U2.J3_7 (PA24)
PA25: U2.J1_2 (PA25)
PA26: U2.J1_5 (PA26)
PA27: U2.J1_8 (PA27)
PA28: U2.J4_3 (PA28)
PA31: U2.J4_4 (PA31)
PB0: U2.J2_9 (PB0)
PB1: U2.J4_2 (PB1)
PB2: U2.J1_9 (PB2)
PB3: U2.J1_10 (PB3)
PB4: U2.J4_1 (PB4)
PB6: U1.6 (TFT_CS), U2.J2_8 (PB6), U4.10 (TFT_CS)
PB7: U1.9 (MISO), U2.J2_7 (PB7), U4.12 (SDC_MISO)
PB8: U1.7 (MOSI), U2.J2_6 (PB8), U4.8 (TFTMOSI), U4.13 (SDC_MOSI)
PB9: U1.8 (SCK), U2.J1_7 (PB9), U4.9 (TFTSCK), U4.11 (SDCSCK)
PB12: U2.J2_2 (PB12)
PB13: U2.J4_6 (PB13)
PB15: U1.3 (RESET), U2.J2_4 (PB15), U4.6 (RESET)
PB16: U2.J2_10 (PB16)
PB17: U2.J2_3 (PB17)
PB18: U2.J3_5 (PB18)
PB19: U2.J3_3 (PB19)
PB20: JP1.2 (C), U2.J4_5 (PB20)
PB23: U2.J1_3 (PA9/PB23)
PB24: U2.J1_6 (PB24)

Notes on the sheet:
U2_Rx
U1_Tx

Board: 2 copper layers, 44 parts (1 on the bottom side), 12 nets, no tracks yet.

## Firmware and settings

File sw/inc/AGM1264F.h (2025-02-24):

//*****************AGM1264F.h***************************************
// implementation of the driver for the AGM1264F MODULE
// Jonathan W. Valvano 11/8/11
// modified to run on LM4F120 launchpad on 10/8/12
// compiled on TM4C123 on 9/11/13
// May 2, 2015
/* This example accompanies the book
   "Embedded Systems: Real Time Interfacing to Arm Cortex M Microcontrollers",
   ISBN: 978-1463590154, Jonathan Valvano, copyright (c) 2015

 Copyright 2015 by Jonathan W. Valvano, valvano@mail.utexas.edu
    You may use, edit, run or distribute this file
    as long as the above copyright notice remains
 THIS SOFTWARE IS PROVIDED "AS IS".  NO WARRANTIES, WHETHER EXPRESS, IMPLIED
 OR STATUTORY, INCLUDING, BUT NOT LIMITED TO, IMPLIED WARRANTIES OF
 MERCHANTABILITY AND FITNESS FOR A PARTICULAR PURPOSE APPLY TO THIS SOFTWARE.
 VALVANO SHALL NOT, IN ANY CIRCUMSTANCES, BE LIABLE FOR SPECIAL, INCIDENTAL,
 OR CONSEQUENTIAL DAMAGES, FOR ANY REASON WHATSOEVER.
 For more information about my classes, my research, and my books, see
 http://users.ece.utexas.edu/~valvano/
 */

// Hardware LCD1030 from BG Micro (not tested):
// gnd    =  1- AGM1264F ground
// +5V    =  2- AGM1264F Vcc (with 0.1uF cap to ground)
// pot    =  3- AGM1264F Vo  (center pin of 10k pot)
// PE0    =  4- AGM1264F D/I (0 for command, 1 for data)
// gnd    =  5- AGM1264F R/W (blind cycle synchronization)
// PE1    =  6- AGM1264F E   (1 to latch in data/command)
// PB0    =  7- AGM1264F DB0
// PB1    =  8- AGM1264F DB1
// PB2    =  9- AGM1264F DB2
// PB3    = 10- AGM1264F DB3
// PB4    = 11- AGM1264F DB4
// PB5    = 12- AGM1264F DB5
// PB6    = 13- AGM1264F DB6
// PB7    = 14- AGM1264F DB7
// PE2    = 15- AGM1264F CS1 (controls left half of LCD)
// PE3    = 16- AGM1264F CS2 (controls right half of LCD)
// +5V    = 17- AGM1264F RES (reset)
// pot    = 18- ADM1264F Vee (-10V)
// NC     = 19- A
// NC     = 20- K
// 10k pot from pin 18 to ground, with center to pin 3
// references   http://www.azdisplays.com/prod/g1264f.php
// sample code  http://www.azdisplays.com/PDF/agm1264f_code.pdf
// data sheet   http://www.azdisplays.com/PDF/agm1264f.pdf

// Sparkfun LCD-00710      GDM12864H.pdf 
// HardwareADM12864H (tested):
// +5V    =  1- Vdd
// gnd    =  2- Vss
// pot    =  3- Vo
// PB0    =  4- DB0
// PB1    =  5- DB1
// PB2    =  6- DB2
// PB3    =  7- DB3
// PB4    =  8- DB4
// PB5    =  9- DB5
// PB6    = 10- DB6
// PB7    = 11- DB7
// PE2    = 12- CS2	 (control left side of LCD)
// PE3    = 13- CS1	 (control right side of LCD)
// +5V    = 14- /RES (reset)
// gnd    = 15- R/W (blind cycle synchronization)
// PE0    = 16- D/I (0 for command, 1 for data)
// PE1    = 17- E
// pot    = 18- Vee
// NC     = 19- A
// NC     = 20- K
// 10k pot from pin 18 to ground, with center to pin 3
// http://www.sparkfun.com/datasheets/LCD/GDM12864H.pdf

// BUG NOTICE 11/11/09 -Valvano
// When changing from right to left or from left to right
//   the first write with data=0 goes to two places
// One can reduce the effect of this bug by
// 1) Changing sides less often
// 2) Ignore autoincrement, and set column and page address each time
// 3) Blanking the screen then write 1's to the screen
// GoTo bug fixed on 11/20/09

//******************************************************************


// to use it as an 8-line by 21-character display
// initialize it once using
//      LCD_Init
// clear screen with
//      LCD_Clear
// set cursor position using
//      LCD_GoTo
// place ASCII on the screen using
//      LCD_OutChar
//      LCD_OutString
//      LCD_OutDec
//      LCD_OutFix1
//      LCD_OutFix2
//      LCD_OutFix3

// ********* LCD_Init***********
// Initialize AGM1264F 128-bit by 64-bit graphics display
// activates SysTick at 50 MHz, assumes PLL active
// Input: none
// Output: none
// does not clear the display
void LCD_Init(void);

// ********* LCD_Clear***********
// Clear the entire 1024 byte (8192 bit) image on the
//    AGM1264F 128-bit by 64-bit graphics display
// Input: value to write into all bytes of display RAM
// Output: none
// e.g., LCD_Clear(0);  // makes all pixels off
void LCD_Clear(unsigned char data);

//-----------------------LCD_GoTo-----------------------
// Move cursor
// Input: line number is 1 to 8, column from 1 to 21
// Output: none
// errors: it will ignore legal addresses
void LCD_GoTo(int line, int column);

// ********* LCD_OutChar***********
// Output ASCII character on the
//    AGM1264F 128-bit by 64-bit graphics display
// Input: 7-bit ASCII to display
// Output: none
// letter must be between 32 and 127 inclusive
// execute LCD_GoTo to specify cursor location
void LCD_OutChar(unsigned char letter);

//---------------------LCD_OutString--------------
// Display String
// Input: pointer to NULL-terminationed ASCII string
// Output: none
void LCD_OutString(char *pt);

//-----------------------LCD_OutDec-----------------------
// Output a 16-bit number in unsigned decimal format
// Input: 16-bit unsigned number
// Output: none
// fixed size 5 digits of output, right justified
void LCD_OutDec(unsigned short n);

//-----------------------LCD_OutSDec-----------------------
// Output a 16-bit number in signed decimal format
// Input: 16-bit signed number
// Output: none
// fixed size 6 digits of output, right justified
void LCD_OutSDec(short n);

//-----------------------LCD_OutFix1-----------------------
// Output a 16-bit number in unsigned decimal fixed-point
// with resolution = 0.1
// Input: 16-bit unsigned number
// Output: none
// fixed size is 6 characters of output, right justified
// if input is 12345, then display is 1234.5
void LCD_OutFix1(unsigned short n);

//-----------------------LCD_OutFix2-----------------------
// Output a 16-bit number in unsigned decimal fixed-point
// with resolution = 0.01
// Input: 16-bit unsigned number
// Output: none
// fixed size is 6 characters of output, right justified
// if input is 12345, then display is 123.45
void LCD_OutFix2(unsigned short n);

//-----------------------LCD_OutFix2b-----------------------
// Output a 16-bit number in unsigned decimal fixed-point
// with resolution = 0.01
// Input: 16-bit unsigned number, 0 to 9999
// Output: none
// fixed size is 5 characters of output, right justified
// if input is 2345, then display is 23.45
void LCD_OutFix2b(unsigned short n);

//-----------------------LCD_OutFix3-----------------------
// Output a 16-bit number in unsigned decimal fixed-point
// with resolution = 0.001
// Input: 16-bit unsigned number
// Output: none
// fixed size is 6 characters of output, right justified
// if input is 12345, then display is 12.345
void LCD_OutFix3(unsigned short n);
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

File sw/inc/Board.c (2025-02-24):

// Board.c
// Runs on LM4F120/TM4C123
// Provide functions that initialize a GPIO as an input pin and
// allow reading of two negative logic switches on PF0 and PF4
// and an external switch on PA5.
// Use bit-banded I/O.
// Daniel and Jonathan Valvano
// September 12, 2013

/* This example accompanies the book
   "Embedded Systems: Introduction to ARM Cortex M Microcontrollers",
   ISBN: 978-1469998749, Jonathan Valvano, copyright (c) 2015
   Section 4.2    Program 4.2

  "Embedded Systems: Real Time Interfacing to ARM Cortex M Microcontrollers",
   ISBN: 978-1463590154, Jonathan Valvano, copyright (c) 2015
   Example 2.3, Program 2.9, Figure 2.36

 Copyright 2015 by Jonathan W. Valvano, valvano@mail.utexas.edu
    You may use, edit, run or distribute this file
    as long as the above copyright notice remains
 THIS SOFTWARE IS PROVIDED "AS IS".  NO WARRANTIES, WHETHER EXPRESS, IMPLIED
 OR STATUTORY, INCLUDING, BUT NOT LIMITED TO, IMPLIED WARRANTIES OF
 MERCHANTABILITY AND FITNESS FOR A PARTICULAR PURPOSE APPLY TO THIS SOFTWARE.
 VALVANO SHALL NOT, IN ANY CIRCUMSTANCES, BE LIABLE FOR SPECIAL, INCIDENTAL,
 OR CONSEQUENTIAL DAMAGES, FOR ANY REASON WHATSOEVER.
 For more information about my classes, my research, and my books, see
 http://users.ece.utexas.edu/~valvano/
 */

// negative logic switches connected to PF0 and PF4 on the Launchpad
// red LED connected to PF1 on the Launchpad
// blue LED connected to PF2 on the Launchpad
// green LED connected to PF3 on the Launchpad
// NOTE: The NMI (non-maskable interrupt) is on PF0.  That means that
// the Alternate Function Select, Pull-Up Resistor, Pull-Down Resistor,
// and Digital Enable are all locked for PF0 until a value of 0x4C4F434B
// is written to the Port F GPIO Lock Register.  After Port F is
// unlocked, bit 0 of the Port F GPIO Commit Register must be set to
// allow access to PF0's control registers.  On the LM4F120, the other
// bits of the Port F GPIO Commit Register are hard-wired to 1, meaning
// that the rest of Port F can always be freely re-configured at any
// time.  Requiring this procedure makes it unlikely to accidentally
// re-configure the JTAG and NMI pins as GPIO, which can lock the
// debugger out of the processor and make it permanently unable to be
// debugged or re-programmed.
#include <stdint.h>
#include "../inc/tm4c123gh6pm.h"
#include "../inc/SysTick.h"

#define GPIO_LOCK_KEY           0x4C4F434B  // Unlocks the GPIO_CR register
#define PF0                     (*((volatile uint32_t *)0x40025004))
#define PF4                     (*((volatile uint32_t *)0x40025040))
#define PA5                     (*((volatile uint32_t *)0x40004080))
#define SWITCHES                (*((volatile uint32_t *)0x40025044))
#define SW1       0x10                      // on the left side of the Launchpad board
#define SW2       0x01                      // on the right side of the Launchpad board
#define SYSCTL_RCGC2_GPIOF      0x00000020  // port F Clock Gating Control

//------------Switch_Init------------
// Initialize GPIO Port A bit 5 for input
// Input: none
// Output: none
void Switch_Init(void){ 
  SysTick_Init();
  SYSCTL_RCGCGPIO_R |= 0x00000001;     // 1) activate clock for Port A
  while((SYSCTL_PRGPIO_R&0x01) == 0){};// ready?
  GPIO_PORTA_AMSEL_R &= ~0x20;      // 3) disable analog on PA5
  GPIO_PORTA_PCTL_R &= ~0x00F00000; // 4) PCTL GPIO on PA5
  GPIO_PORTA_DIR_R &= ~0x20;        // 5) direction PA5 input
  GPIO_PORTA_AFSEL_R &= ~0x20;      // 6) PA5 regular port function
  GPIO_PORTA_DEN_R |= 0x20;         // 7) enable PA5 digital port
}
//------------Switch_Input------------
// Read and return the status of GPIO Port A bit 5 
// Input: none
// Output: 0x20 if PA5 is high
//         0x00 if PA5 is low
uint32_t Switch_Input(void){
  return PA5; // return 0x20(pressed) or 0(not pressed)
}
uint32_t Switch_Input2(void){
  return (GPIO_PORTA_DATA_R&0x20); // 0x20(pressed) or 0(not pressed)
}

//------------Board_Init------------
// Initialize GPIO Port F for negative logic switches on PF0 and
// PF4 as the Launchpad is wired.  Weak internal pull-up
// resistors are enabled, and the NMI functionality on PF0 is
// disabled.
// Input: none
// Output: none
void Board_Init(void){            
  SYSCTL_RCGCGPIO_R |= 0x20;     // 1) activate Port F
  while((SYSCTL_PRGPIO_R&0x20) == 0){};// ready?
                                 // 2a) unlock GPIO Port F Commit Register
  GPIO_PORTF_LOCK_R = GPIO_LOCK_KEY;
  GPIO_PORTF_CR_R |= (SW1|SW2);  // 2b) enable commit for PF4 and PF0
                                 // 3) disable analog functionality on PF4 and PF0
  GPIO_PORTF_AMSEL_R &= ~(SW1|SW2);
                                 // 4) configure PF0 and PF4 as GPIO
  GPIO_PORTF_PCTL_R = (GPIO_PORTF_PCTL_R&0xFFF0FFF0)+0x00000000;
  GPIO_PORTF_DIR_R &= ~(SW1|SW2);// 5) make PF0 and PF4 in (built-in buttons)
                                 // 6) disable alt funct on PF0 and PF4
  GPIO_PORTF_AFSEL_R &= ~(SW1|SW2);
//  delay = SYSCTL_RCGC2_R;        // put a delay here if you are seeing erroneous NMI
  GPIO_PORTF_PUR_R |= (SW1|SW2); // enable weak pull-up on PF0 and PF4
  GPIO_PORTF_DEN_R |= (SW1|SW2); // 7) enable digital I/O on PF0 and PF4
}

//------------Board_Input------------
// Read and return the status of the switches.
// Input: none
// Output: 0x01 if only Switch 1 is pressed
//         0x10 if only Switch 2 is pressed
//         0x00 if both switches are pressed
//         0x11 if no switches are pressed
uint32_t Board_Input(void){
  return SWITCHES;
}

// Program 2.9 from Volume 2
#define PB1 (*((volatile uint32_t *)0x40005008))
//------------Switch_Init3------------
// Initialize GPIO Port B bit 1 for input
// Input: none
// Output: none
void Switch_Init3(void){
  SYSCTL_RCGCGPIO_R |= 0x02;        // 1) activate clock for Port B
  while((SYSCTL_PRGPIO_R&0x02) == 0){};// ready?
  GPIO_PORTB_DIR_R &= ~0x02;        // PB1 is an input
  GPIO_PORTB_AFSEL_R &= ~0x02;      // regular port function
  GPIO_PORTB_AMSEL_R &= ~0x02;      // disable analog on PB1 
  GPIO_PORTB_PCTL_R &= ~0x000000F0; // PCTL GPIO on PB1 
  GPIO_PORTB_DEN_R |= 0x02;         // PB3-0 enabled as a digital port
}
//------------Switch_Input3------------
// Read and return the status of GPIO Port B bit 1 
// Input: none
// Output: 0x02 if PB1 is high
//         0x00 if PB1 is low
uint32_t Switch_Input3(void){ 
  return PB1;      // 0x02 if pressed, 0x00 if not pressed
}

#define DELAY10MS 160000
#define DELAY10US 160
//------------Switch_Debounce------------
// Read and return the status of the switch 
// Input: none
// Output: 0x02 if PB1 is high
//         0x00 if PB1 is low
// debounces switch
uint32_t Switch_Debounce(void){
uint32_t in,old,time; 
  time = 1000; // 10 ms
  old = Switch_Input();
  while(time){
    SysTick_Wait(DELAY10US); // 10us
    in = Switch_Input();
    if(in == old){
      time--; // same value 
    }else{
      time = 1000;  // different
      old = in;
    }
  }
  return old;
}
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

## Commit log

2025-02-24 flatten pt2
    [ECE319K_Starter.kicad_pcb, ECE319K_Starter.kicad_sch, ECE445L_Lab6.kicad_pcb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]
2025-02-24 flatten pt3
    [OPT3101speedChoices.xlsx, SineTable.xlsx]
2025-03-07 all hardware changes
    fully updated schematic and pcb, most of changes were local to prevent corrupting files when pulling.
    [ECE445L_Lab6.kicad_pcb, ECE445L_Lab6.kicad_sch, Lab6BOM.xlsx]
